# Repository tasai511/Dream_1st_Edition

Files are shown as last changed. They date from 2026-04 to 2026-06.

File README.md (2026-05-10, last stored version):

# ドリーム1号 素振り記録アプリ

素振り練習用デバイス「ドリーム1号」の記録用PWAです。HTML / CSS / JavaScriptのみで構成され、アプリ本体は `app/` フォルダに入っています。

## できること

- 名前とバットを複数登録
- 日付、名前、バット、素振り回数、平均スコア、ベストスコアを記録
- 同じ日付・名前・バットの記録は自動で合算
- 平均スコアは回数による加重平均で計算
- ベストスコアは最大値を採用
- 最近の入力履歴から編集・削除
- 期間、名前、バットで絞り込んだグラフ表示
- CSVエクスポート / インポート
- オフライン動作

## GitHub Pagesで公開する方法

1. このリポジトリをGitHubへpushします。
2. GitHubのリポジトリ画面で `Settings` を開きます。
3. `Pages` を開きます。
4. `Build and deployment` の `Source` で `Deploy from a branch` を選びます。
5. `Branch` で公開したいブランチと `/root` を選び、保存します。
6. 表示されたURLを開くと、自動で `app/` のアプリが開きます。

アプリを直接開く場合は、GitHub PagesのURL末尾に `/app/` を付けてください。

## PWAとしてホーム画面に追加する方法

### iPhone / iPad

1. SafariでGitHub PagesのURLを開きます。
2. 共有ボタンを押します。
3. `ホーム画面に追加` を選びます。
4. 名前を確認して追加します。

### Android

1. ChromeでGitHub PagesのURLを開きます。
2. メニューから `ホーム画面に追加` または `アプリをインストール` を選びます。
3. 確認して追加します。

## CSVエクスポート / インポート

### エクスポート

`CSVエクスポート` ボタンを押すと、全記録をCSVファイルとして保存します。CSVには以下の列が含まれます。

- 名前
- バット
- 日付
- 回数
- 平均
- ベスト

### インポート

`CSVインポート` からCSVファイルを選ぶと、記録を復元できます。既存データと同じ日付・名前・バットの行は合算されます。不正な行はスキップされ、読み込み後にスキップ件数が表示されます。

## データ保存について

データはすべて端末ローカルのIndexedDBに保存されます。サーバー保存、ログイン、クラウド同期はありません。

端末を変更する場合やブラウザのデータを消す場合は、事前にCSVエクスポートでバックアップしてください。新しい端末ではCSVインポートで移行できます。

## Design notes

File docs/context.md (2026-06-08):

# Dream-1 コンテキスト

## 概要

Dream-1 は、バットの素振りを楽しく続けるための小型スイングモチベーションデバイスです。

科学的な計測器ではありません。真のバットヘッドスピードや打球速度を測るものではなく、同じユーザー、同じバット、同じ装着位置での相対比較を目的にしたトレーニング用スコアを出します。

主な目的:

- 素振り回数を増やす
- 良いスイングの体感を数字で補助する
- 同じ条件下での自己比較をしやすくする
- 子供でもスコアが出て楽しい体験にする

Dream-1 は、正確に測る装置ではなく、良い練習を増やす装置である。

---

## 記録アプリ: Swing Log 現行実装

Dream-1 の記録アプリは、厳密なトレーニング評価ではなく「素振りを続けたくなる記録とバッジ収集」のための PWA として実装している。

重視すること:

- 毎日少しでも振りたくなる
- あと少しで取れる感を出す
- 回数、平均、ベスト、練習日数の積み上げを見せる
- 他人比較ではなく、同じ名前、同じバット、同じ端末内での自己比較を中心にする
- Dream-1 は厳密フォーム解析機ではなく、素振りを楽しく続けるための道具として扱う

### 技術構成

- 実装本体は `app/src/App.jsx`
- React 18 + Vite
- CSS は `app/src/styles.css`
- PWA 用に `app/public/manifest.webmanifest` と `app/public/service-worker.js` を使う
- service worker は静的アセット、画像、音声を cache する
- データ保存は IndexedDB ではなく `localStorage`
- storage key は `dream1-swing-tracker-v1`
- サーバー保存、ログイン、クラウド同期はない

### アプリデータ

`localStorage` に保存する DB は概ね以下。

```ts
type AppDb = {
  activeName: string;
  names: string[];
  nameColors: Record<string, string>;
  bats: string[];
  batColors: Record<string, string>;
  defaultBat: string;
  theme: string;
  fontTheme: string;
  records: SwingRecord[];
  seasonEventSettings: SeasonEventSettings;
  badgeRewardGoal: string;
  badgeRewardText: string;
  testInputDefaults: boolean;
  testRandomGeneration: boolean;
  testDate: string | null;
};

type SwingRecord = {
  id: string;
  name: string;
  bat: string;
  date: string;  // YYYY-MM-DD
  count: number;
  avg: number;   // 0..999
  best: number;  // 0..999
};

type SeasonEventSettings = Record<
  "spring" | "summer" | "winter",
  { startMonth: number; startDay: number; endMonth: number; endDay: number }
>;
```

名前とバットが1件以上ない場合は、設定画面へ誘導する。
記録は同じ日付、名前、バットでも物理的には結合せず、`records` に追加する。表示時に日付別、バット別へ集計する。

### 入力と CSV

ホーム画面から以下を入力する。

- バット
- 回数
- 平均スコア
- ベストスコア

保存時の丸め:

- `count`: 最低 `1`
- `avg`: `0..999` に clamp
- `best`: `0..999` に clamp

CSV 出力:

```csv
name,bat,date,count,avg,best
```

CSV 読込では、存在しない名前やバットを自動追加し、各行を新しい record として追加する。既存 record との物理的な重複統合はしない。

### 集計

日次集計:

```ts
dailyCount = sum(record.count)
dailyAvg = round(sum(record.avg * record.count) / dailyCount)
dailyBest = max(record.best)
dailyBats = unique(record.bat)
```

バット別集計も同じ考え方で、バットごとに回数合計、回数加重平均、ベスト最大値を出す。

期間集計:

- 今日: 対象日だけ
- 今週: 月曜始まり、日曜終わり
- 今月: 暦月
- チャレンジ画面の今年: 初回記録日を起点にした1年サイクル
- 年間バッジ判定: 暦年単位

期間平均は、期間内 record の `avg * count` を回数で割った加重平均。
練習日数は、`count > 0` の日数。

### 画面構成

下部ナビゲーション:

- ホーム
- チャレンジ
- バッジ
- データ
- 設定

ホーム:

- 日付選択
- スコア入力
- 今日または選択日の回数、平均、ベスト
- 取得バッジ
- バット別の回数、平均、ベスト
- 記録追加時のスコアアニメーションと初取得バッジポップアップ

チャレンジ:

- 今週、今月、今年のスイング数
- 今週、今月、今年の練習日数
- 選択バットの過去最高平均、過去最高ベスト

バッジ:

- バッジポイント
- 目標ポイントとごほうび入力
- コレクション一覧
- カテゴリ filter: スイング数、練習日数、平均、ベスト、すべて
- レア度ごとの表示

データ:

- 毎日、毎週、毎月のグラフ
- スイング数グラフ
- 平均/ベストのスコアグラフ
- バット filter

設定:

- 名前の登録、切り替え、削除、色設定
- バットの登録、削除、色設定、デフォルトバット
- CSV 出力、CSV 読込
- 全データ削除
- デモデータ作成
- テストモード

### バッジ

バッジ取得履歴は別テーブルに保存しない。
`records` から `badgesFor()` で毎回再計算し、`collectBadgeCounts()` でコレクション表示用の個数に変換する。

レア度:

```ts
type BadgeRarity = "D" | "C" | "B" | "A" | "S" | "SS";

const rarityPoint = {
  D: 1,
  C: 2,
  B: 5,
  A: 10,
  S: 25,
  SS: 100,
};
```

レア度名:

- D: Dream
- C: Challenge
- B: Brave
- A: Ace
- S: Star
- SS: Super Star

実装済みバッジ:

| 種別 | 指標 | 閾値 |
| --- | --- | --- |
| 今日 | スイング数 | 25, 50, 75, 100 |
| 今日 | 平均 | 250, 350, 450, 550, 650, 750 |
| 今日 | ベスト | 350, 450, 550, 650, 750, 850 |
| 今週 | スイング数 | 125, 250, 375, 500 |
| 今週 | 練習日数 | 1, 2, 3, 4, 5 |
| 今月 | スイング数 | 500, 1000, 1500, 2000 |
| 今月 | 練習日数 | 4, 8, 12, 16, 20 |
| 今年 | スイング数 | 6000, 12000, 18000, 24000 |
| 今年 | 練習日数 | 50, 100, 150, 200, 225, 250 |
| 初突破 | バット別過去最高平均 | 400, 500, 600, 700, 750, 800 |
| 初突破 | バット別過去最高ベスト | 500, 600, 700, 800, 850, 900 |

`unique` はコレクション上で1個まで。
`repeatable` は取得回数分だけ個数とポイントに加算する。
初突破系はバットごとの過去最高更新時に、その閾値を初めて超えた日に付与する。

### テスト機能

設定画面からデモデータを作成できる。
テストモードでは任意の日付へ進め、未入力日の練習記録を自動生成できる。
この機能は UI とバッジ演出の検証用で、本番の記録仕様とは分けて考える。

---

## 非交渉原則

- 子供が振って楽しいことを最優先する
- 999 は簡単に出さない
- 普通のスイングで無反応にしすぎない
- 変な振り方を高得点にしない
- 電池寿命を著しく削る変更は避ける
- スコアの納得感を、物理精度より優先する

---

## 参考スコアレンジ

現時点の体感チューニング目安:

- 普通の子供スイング: 320〜520
- 良いスイング: 550〜750
- かなり良いスイング: 800+
- 999 は稀

このレンジは絶対値ではない。  
同じユーザー、同じバット、同じ装着位置で比較したときに納得感が出ることを優先する。

スコアの思想:

- 高得点 = 強く、早く、再現性高くインパクトを作れそうなスイング
- 低得点 = 遠回り、遅い、ブレる、弱いスイング
- 大ぶり = 力強いスイングではなく、遠回りで当たりにくそうなスイング
- 良いスイング = 十分な加速エリアの中で角速度も高く出る、鋭く振り切れたスイング

---

## ハードウェア

### MCU

- ATtiny3226
- 10MHz
- Arduino framework
- PlatformIO

### IMU

- LSM6DSV80X
- SPI 接続
- CS: PA4
- FIFO と割り込みを使用
- タップ検出も IMU 側から取得する

### ブザー

- 圧電ブザー
- 差動駆動
- BUZZER_P: PA6
- BUZZER_N: PA7

注意:

- Serial TX はブザーやピン割り当てと干渉し得る
- 実運用では Serial 接続を前提にしない
- デバッグ出力は本番経路に入れない

### 7セグ LED

- 3桁 7セグ LED
- common cathode
- multiplex 駆動

セグメント:

- SEG_A: PB0
- SEG_B: PB2
- SEG_C: PB4
- SEG_D: PB3
- SEG_E: PB1
- SEG_F: PB5
- SEG_G: PC0

桁選択:

- DIGIT_1: PC1
- DIGIT_2: PC2
- DIGIT_3: PC3

表示方針:

- 通常は消灯
- スコア、平均、回数など必要なときだけ短時間表示
- ブザー動作中は表示更新よりブザーを優先する
- 表示ロジックは単純で決定的に保つ

### 電源

- CR2450 コイン電池
- 低消費電力が重要
- 不要な active 時間を増やさない
- idle 時は sleep を使う
- 長時間無操作で最終 sleep に入る

---

## 現在の製品挙動

### 通常状態

- 起動後に短時間キャリブレーションする
- キャリブレーション中は電池残量目安を表示する
- その後は Monitor 状態で IMU を監視する
- 有効なスイングを検出すると Capturing 状態に入り、ピークや特徴量を記録する
- スイング終了後、スコアを計算して表示する
- 表示時間終了後、Monitor に戻る

### ブザー

スイング成立時にブザーを鳴らす。

- ベスト更新: 3回
- 平均以上: 2回
- 平均未満: 1回
- 一定回数ごとの節目: milestone beep

この仕様は現在の実装を正とする。

### 表示

- スイング成立後、スコアを短時間表示する
- 低スコアでもスイングとして成立していれば `100` 以上で表示する
- 無効な動きは表示しない
- Single tap ではスイング回数を表示する
- Double tap では平均スコアを1秒表示し、その後ベストスコアを1秒表示する
- Double tap の平均/ベスト表示中は表示の安定を優先し、スイング検出は受け付けない
- 表示中やスコア直後はタップ誤検出を抑えるために mute 時間を設ける

### タップ

- タップはスコア計算には使わない
- スイング検出とは別系統の入力として扱う
- Single / Double のイベントを扱う
- Double tap は平均表示からベスト表示への2段表示
- 通常スイングのフォロースルーがタップ扱いになりにくいよう、表示直後やスコア直後はタップを抑制する

---

## スコアの意味

スコアは物理量ではありません。以下のような動きの傾向を IMU から拾い、0〜999 の範囲に収めた実用スコアです。

高くしたい動き:

- 十分な角速度ピークがある
- 一定以上の加速度がある程度続いている
- 回転と加速度の両方が出ている
- 同じ条件下で、より強く鋭く振れている

低くしたい動き:

- 弱い
- 遅い
- 回転だけ、または加速度だけに偏っている
- 一瞬だけの衝撃
- 小さい手振り
- ランダムな持ち替え、振動、置いた衝撃

---

## スイング検出

### 開始条件

Monitor 中に以下のような意味のある動きが出たら Capturing を開始する。

- `strength >= kCaptureStartStrength` (`2400`)
- かつ、`gyroMagnitudeRaw >= kCaptureStartGyroRaw` (`900`) または `dynamicAccelMg >= kCaptureStartAccelMg` (`1800`)

`strength` は概ね以下の合成値:

```cpp
gyroMagnitudeRaw + dynamicAccelMg * 4
```

ゆっくりした持ち替えや小さい動きは開始しにくくする。

### キャプチャ中に記録する値

スイング成立判定とスコア再計算のために、主に以下を記録する。

- `gyroPeakRaw`
- `accelPeakMg`
- `firstGyroStrongTimeMs`
- `maxAccelRiseMs`
- `swingAccelAreaMgMs`
- `capturePeakStrength`

スコア計算時は、キャプチャサンプルから `ScoreWindow` を作り直し、その範囲内で `gyroPeakRaw` と `swingAccelAreaMgMs` を再計算する。

### 終了条件

以下のどちらかでキャプチャを終了する。

- 最大キャプチャ時間 `kCaptureMaxMs` (`900 ms`) に達した
- 最小キャプチャ時間 `kCaptureMinMs` (`80 ms`) を超え、`strength` が `capturePeakStrength * kCaptureEndDropPct / 100` (`70%`) 以下になった

### 無効化

`swingEvidence()` によって、動きがスイングらしいかを確認する。

現在の evidence は合計 `6` 点以上でスイング成立。

- スイング時間: `160 ms` 以上で +2、`80 ms` 以上で +1
- gyro peak: `gyroPeakRaw >= 900` で +2
- accel peak: `2000 mg` 以上で +2、`1000 mg` 以上で +1
- accel rise 時間: `35 ms` 以上で +2、`15 ms` 以上で +1
- 強い gyro が一度でも出たら +1
- `capturePeakStrength >= 1800` で +1

`accel rise` はスコアには使わない。  
加速度が一瞬の衝撃ではなく、ある程度立ち上がった動きかを確認するための evidence 専用指標として使う。

低スコア救済は使わない。  
最終スコアが `100` に届いた場合だけスコア表示する。  

---

## スコア計算

現在のスコアは `finishCapture()` で `gyroPeakScore()` と `swingAccelAreaScore()` を計算し、`scoreFromComponents()` で合算する。

構成:

```cpp
score = gyroPeakScore();          // max 500
score += swingAccelAreaScore();   // max 500
score = min(score, 999);
```

整数演算中心で、float は使わない。

採点に入る条件:

- `swingEvidence()` が `6` 点以上
- score が `100` 以上

この条件を満たさない場合は no score。

### ScoreWindow

スコア対象範囲はキャプチャ全体ではなく、キャプチャサンプルから作る `ScoreWindow` で決める。
一時的な山で閉じないよう、まず `scoreStartMs` 以降の最大加速度ピークを確定し、その後の落ち込みで `scoreEndMs` を決める。

- `scoreStartMs`: `dynamicAccelMg > 1000 mg` になった最初のサンプル
- `accelPeakMs`: `ScoreWindow` 内での最大加速度サンプル
- `scoreEndMs`: 加速度ピーク後、ピークから `max(ピークの10%, 1000mg)` 以上落ちた時点の直前サンプル。直前サンプルがピークより前ならピーク時刻にする

つまり、スコア範囲は「1000mg を超えて加速が始まったところ」から「加速度ピーク後に明確に落ち始める直前」まで。
1000mg を下回るまで待たない。

`scoreStartMs` は pre capture sample を含むため、グラフ上では負の時刻になることがある。

### gyroPeakScore

`ScoreWindow` 内の角速度ピークを見る。
グローバルなキャプチャ全体の gyro peak ではなく、加速エリア中の最大 gyro を使う。

- 最大 500 点
- gyro full は実測に合わせて `7000 dps`
- IMU の 4000 dps 設定に合わせて `140 mdps/LSB` として換算する
- 7000 dps 以上は 500 点に clamp する

考え方:

- MLB Statcast では 75 mph 以上を fast swing として扱う
- MLB 上位選手の平均 bat speed は 80 mph 前後に達する
- bat speed 80〜85 mph を sweet spot 半径およそ 0.75 m で角速度換算すると約 2700〜2900 dps
- ただし Dream-1 は単一軸ではなく3軸合成の `gyroMagnitudeRaw` を使うため、単純な角速度換算より大きめに出る
- 3000〜4500 dps では子供や軽めのスイングでも上限に届きやすかったため、Dream-1 の実測レンジに合わせて `7000 dps` を使う
- この値は実測ベースの仮置き。上手い人で Gyro 側が簡単に 500 点へ張り付く場合はさらに上げる候補がある

### swingAccelAreaScore

`ScoreWindow` 内に乗った dynamic accel の積算を見る。

```cpp
area = sum((dynamicAccelMg - offset) * dt)
score = area / fullArea * 500
```

手首だけの一瞬の入力ではなく、スイング中に加速度が乗って続いたかを見る。  
現在は `offset` を初めて超えた時刻から、加速度ピーク後に明確に落ち始める直前までの offset 超過分を積算する。

`offset` は `1000 mg`。  
小さい揺れ、構え、ぶらぶらを積算しにくくしつつ、普通のスイングが `0` になりにくい値として実測から置いている。

`fullArea` は `800000 mg*ms`。
これは公開データから直接導いた物理定数ではなく、Dream-1 の実測ベースの仮置き。  
加速度スコア範囲を広げたことで `600000 mg*ms` では軽いバットの強いスイングが上限に張り付きやすくなったため、飽和を少し抑える値として `800000 mg*ms` を採用している。
配点は SwingAccel 側を 500 点、Gyro 側を 500 点にしている。

今後、通常のバットでも簡単に SwingAccel 側が 500 点へ張り付く場合は `900000〜1000000 mg*ms` 程度へ上げる候補がある。逆に一般ユーザーで伸びなさすぎる場合は `700000 mg*ms` 程度へ下げる候補がある。

### accel rise

スイング時間に対して加速度がピークへ向かって立ち上がった時間を見る。

- スコア補正には使わない
- `swingEvidence()` のために記録する

`maxAccelRiseMs` は固定閾値以上の時間ではなく、dynamic accel が立ち上がってからピーク後に減少へ転じるまでの時間として記録する。  
ノイズで1サンプルだけ下がっても減少扱いにしないよう、小さい変化は無視し、連続した減少で判定する。

加速上昇の開始は `kAccelRiseStartMg` 以上で見る。  
これはスイング成立判定用の accel rise 判定であり、スイング開始判定用の `kCaptureStartAccelMg` とは別に扱う。

---

## スコア下限

`scoreFromComponents()` が返すスコアを、そのまま表示、平均、ベスト更新、ブザー判定に使う。

現在の下限:

- score `100` 未満: no score
- score `100` 以上: 採点成立

ただし、無効な動きは表示しない。

---

## 実装構成

### `src/main.cpp`

- 状態遷移
- キャリブレーション
- スイング開始/終了判定
- ピーク記録
- スコア計算
- タップ処理
- 省電力制御

現在はスコア処理も `main.cpp` 内にある。  
将来的に大きくなる場合は `score.cpp / score.h` に分けてもよいが、現状では軽量さと見通しを優先する。

### `telemetry_best_swing_graph.html`

- EEPROM に保存した best swing telemetry を可視化する解析用 HTML
- `score start`、`accel score end`、`accel peak`、`end judge` をグラフに出す
- `gyro score peak` は `ScoreWindow` 内で実際に見えている最大 gyro sample を表示する
- C++ 側では best telemetry 保存時に score gyro peak sample を優先して残す

### `src/imu.cpp` / `include/imu.h`

- IMU 初期化
- FIFO/割り込み処理
- motion sample 読み出し
- tap event 読み出し
- sleep mode 移行

### `src/display.cpp` / `include/display.h`

- 7セグ表示
- multiplex 更新
- 数値表示
- 表示 timeout
- 消灯

### `src/buzzer.cpp` / `include/buzzer.h`

- ブザー初期化
- beep
- milestone beep
- ブザー波形生成
- beep 中はブザーを優先し、短時間ブロッキングしてよい
- off

### `include/tap.h`

- `TapEvent`
- `None`
- `Single`
- `Double`

---

## メインループ方針

- 通常の監視、表示、スイング処理では長い `delay()` を入れない
- スイング成立直後の beep は例外として、ブザーを優先して短時間ブロッキングしてよい
- ブザー動作中は表示更新や IMU 読み出しよりブザー出力を優先する
- 表示は `Display::update()` で継続更新する
- IMU 割り込みがあるときにサンプルを読む
- 割り込みが詰まった場合は一定時間後に強制読み出しする
- Monitor 中で動きがなければ idle sleep に入る
- 長時間無操作なら final sleep に入る

---

## コーディング方針

必須:

- Arduino style の `setup()` / `loop()` を使う
- 整数演算中心
- RAM 使用量を小さく保つ
- コードサイズを増やしすぎない
- 本番経路に Serial debug を入れない
- 状態遷移、表示、ブザー、省電力処理を不用意に崩さない

避ける:

- float 多用
- スイング監視中の長い blocking wait
- 重いライブラリ
- 複雑すぎるゲート処理
- 科学計測器のような絶対精度を目指すこと

---

## チューニング方針

まず触る候補:

- gyro/accel の開始閾値
- `swingAccelAreaScore()` の offset
- `gyroPeakScore()` の full dps
- `swingAccelAreaScore()` の fullArea
- `kGyroPeakScoreMax` / `kSwingAccelAreaScoreMax` の配点比率
- `kScoreAccelDropPct` / `kScoreAccelDropMinMg` による score end 判定

チューニング時の注意:

- 「無反応」と「100連発」は同じ対策で悪化しやすい
- 小さい動きの誤検出を減らしつつ、大ぶり低スコアは表示したい
- 999 は「速いだけ」では出ないようにする
- 子供が普通に振ったときに点が出なさすぎる状態は避ける
- 装着位置やバット長さで値は変わるため、補正は強くしすぎない

---

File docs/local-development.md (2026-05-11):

# このPCで開発を続ける手順

このプロジェクトは、ファームウェア、記録用PWA、CADデータが同じリポジトリに入っています。

## 記録用アプリを開く

このPCでは `python` や `node` が見つからないため、PowerShellだけで動くローカルサーバーを用意しています。

```powershell
Set-ExecutionPolicy -Scope Process -ExecutionPolicy Bypass
.\tools\serve-local.ps1
```

起動したら、ブラウザで次を開きます。

```text
http://localhost:5173/app/
```

ポートを変えたい場合:

```powershell
.\tools\serve-local.ps1 -Port 5174
```

止めるときは、サーバーを起動しているPowerShellで `Ctrl+C` を押します。

## 記録データについて

記録用アプリのデータはブラウザのIndexedDBに保存されます。PC、ブラウザ、スマホを変える前には、アプリ内の「CSVエクスポート」でバックアップしてください。移行先では「CSVインポート」で戻せます。

## ファームウェアをビルドする

PlatformIOはこのPCで動作確認済みです。

```powershell
& "$env:USERPROFILE\.platformio\penv\Scripts\pio.exe" run
```

現在の設定は `platformio.ini` にあり、書き込みポートは `COM3` です。

## 確認済み

- PlatformIOビルド: 成功
- 記録用アプリ: `app/` に配置済み
- ローカル確認用サーバー: `tools/serve-local.ps1`

## 注意

PowerShellで日本語ファイルを `Get-Content` すると、環境によって文字化けして見える場合があります。ブラウザやGit diffでは正常に読めることがあります。

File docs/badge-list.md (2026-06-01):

# シンプル版バッジ一覧

## 基本方針

バッジは、以下の4カテゴリに整理する。

| カテゴリ | 評価するもの |
| --- | --- |
| スイング数 | たくさん振った |
| 練習日数 | 続けて練習した |
| 平均 | 今日の平均スコア・バット別の平均初突破 |
| ベスト | 今日のベストスコア・バット別のベスト初突破 |

複合条件、週間チャレンジ、月間チャレンジ、月間総合、バランス系は作らない。

## レア度とpt

| レア度 | pt |
| --- | -: |
| D | 1 |
| C | 2 |
| B | 5 |
| A | 10 |
| S | 25 |
| SS | 100 |

## スイング数バッジ

### 今日のスイング

| レア度 | 名前 | 条件 | pt |
| --- | --- | --- | -: |
| D | 今日のスイング 25回 | 25回以上 | 1 |
| D | 今日のスイング 50回 | 50回以上 | 1 |
| C | 今日のスイング 75回 | 75回以上 | 2 |
| B | 今日のスイング 100回 | 100回以上 | 5 |

### 今週のスイング

| レア度 | 名前 | 条件 | pt |
| --- | --- | --- | -: |
| D | 今週のスイング 125回 | 125回以上 | 1 |
| C | 今週のスイング 250回 | 250回以上 | 2 |
| B | 今週のスイング 375回 | 375回以上 | 5 |
| A | 今週のスイング 500回 | 500回以上 | 10 |

### 今月のスイング

| レア度 | 名前 | 条件 | pt |
| --- | --- | --- | -: |
| C | 今月のスイング 500回 | 500回以上 | 2 |
| B | 今月のスイング 1000回 | 1000回以上 | 5 |
| A | 今月のスイング 1500回 | 1500回以上 | 10 |
| S | 今月のスイング 2000回 | 2000回以上 | 25 |

### 今年のスイング

| レア度 | 名前 | 条件 | pt |
| --- | --- | --- | -: |
| B | 今年のスイング 6000回 | 今年6000回以上 | 5 |
| A | 今年のスイング 12000回 | 今年12000回以上 | 10 |
| S | 今年のスイング 18000回 | 今年18000回以上 | 25 |
| SS | 今年のスイング 24000回 | 今年24000回以上 | 100 |

## 練習日数バッジ

### 今週の練習日数

| レア度 | 名前 | 条件 | pt |
| --- | --- | --- | -: |
| D | 今週の練習日数 1日 | 1日以上 | 1 |
| C | 今週の練習日数 2日 | 2日以上 | 2 |
| B | 今週の練習日数 3日 | 3日以上 | 5 |
| A | 今週の練習日数 4日 | 4日以上 | 10 |
| S | 今週の練習日数 5日 | 5日以上 | 25 |

### 今月の練習日数

| レア度 | 名前 | 条件 | pt |
| --- | --- | --- | -: |
| D | 今月の練習日数 4日 | 4日以上 | 1 |
| C | 今月の練習日数 8日 | 8日以上 | 2 |
| B | 今月の練習日数 12日 | 12日以上 | 5 |
| A | 今月の練習日数 16日 | 16日以上 | 10 |
| S | 今月の練習日数 20日 | 20日以上 | 25 |

### 今年の練習日数

| レア度 | 名前 | 条件 | pt |
| --- | --- | --- | -: |
| D | 今年の練習日数 50日 | 今年練習50日以上 | 1 |
| C | 今年の練習日数 100日 | 今年練習100日以上 | 2 |
| B | 今年の練習日数 150日 | 今年練習150日以上 | 5 |
| A | 今年の練習日数 200日 | 今年練習200日以上 | 10 |
| S | 今年の練習日数 225日 | 今年練習225日以上 | 25 |
| SS | 今年の練習日数 250日 | 今年練習250日以上 | 100 |

## 平均バッジ

### 今日の平均スコア

| レア度 | 名前 | 条件 | pt |
| --- | --- | --- | -: |
| D | 今日の平均スコア 250 | 平均250以上 | 1 |
| D | 今日の平均スコア 350 | 平均350以上 | 1 |
| C | 今日の平均スコア 450 | 平均450以上 | 2 |
| B | 今日の平均スコア 550 | 平均550以上 | 5 |
| A | 今日の平均スコア 650 | 平均650以上 | 10 |
| S | 今日の平均スコア 750 | 平均750以上 | 25 |

### 平均初突破

バットごとの1日平均スコアの最高値が各閾値に初めて到達した時点で獲得する。
バットが違えば同じバッジを何回でも獲得できる。

| レア度 | 名前 | 条件 | pt |
| --- | --- | --- | -: |
| D | 初突破 平均 400点 | そのバットでの平均400以上 | 1 |
| C | 初突破 平均 500点 | そのバットでの平均500以上 | 2 |
| B | 初突破 平均 600点 | そのバットでの平均600以上 | 5 |
| A | 初突破 平均 700点 | そのバットでの平均700以上 | 10 |
| S | 初突破 平均 750点 | そのバットでの平均750以上 | 25 |
| SS | 初突破 平均 800点 | そのバットでの平均800以上 | 100 |

## ベストバッジ

### 今日のベストスコア

| レア度 | 名前 | 条件 | pt |
| --- | --- | --- | -: |
| D | 今日のベストスコア 350 | ベスト350以上 | 1 |
| D | 今日のベストスコア 450 | ベスト450以上 | 1 |
| C | 今日のベストスコア 550 | ベスト550以上 | 2 |
| B | 今日のベストスコア 650 | ベスト650以上 | 5 |
| A | 今日のベストスコア 750 | ベスト750以上 | 10 |
| S | 今日のベストスコア 850 | ベスト850以上 | 25 |

### ベスト初突破

バットごとの1日ベストスコアの最高値が各閾値に初めて到達した時点で獲得する。
バットが違えば同じバッジを何回でも獲得できる。

| レア度 | 名前 | 条件 | pt |
| --- | --- | --- | -: |
| D | 初突破 ベスト 500点 | そのバットでのベスト500以上 | 1 |
| C | 初突破 ベスト 600点 | そのバットでのベスト600以上 | 2 |
| B | 初突破 ベスト 700点 | そのバットでのベスト700以上 | 5 |
| A | 初突破 ベスト 800点 | そのバットでのベスト800以上 | 10 |
| S | 初突破 ベスト 850点 | そのバットでのベスト850以上 | 25 |
| SS | 初突破 ベスト 900点 | そのバットでのベスト900以上 | 100 |

## 実装メモ

- スイング数、練習日数、ベストは一度獲得したら獲得済みとして扱う。
- 平均スコア系は、スコアが下がって条件を満たさなくなったら獲得を外す。
- 初突破系はバットごとに判定する。同じ閾値でもバットが違えば別回として獲得する。
- ホームは今日の記録、チャレンジは進捗、バッジはコレクション、設定は既存機能を維持する。

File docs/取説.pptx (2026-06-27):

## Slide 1

取扱説明書

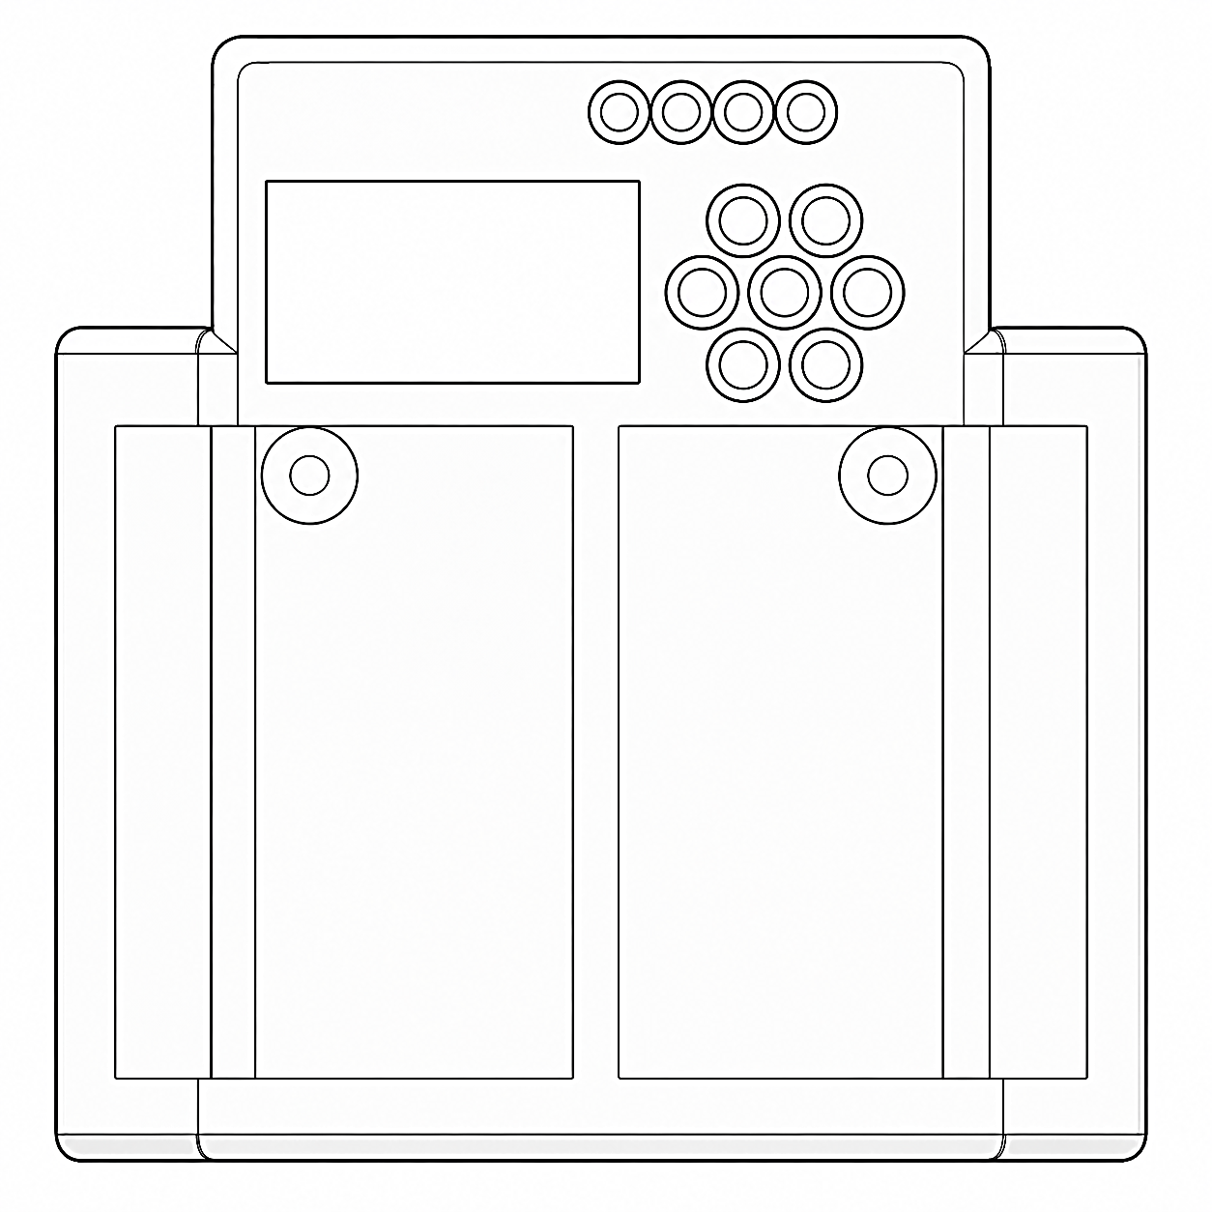
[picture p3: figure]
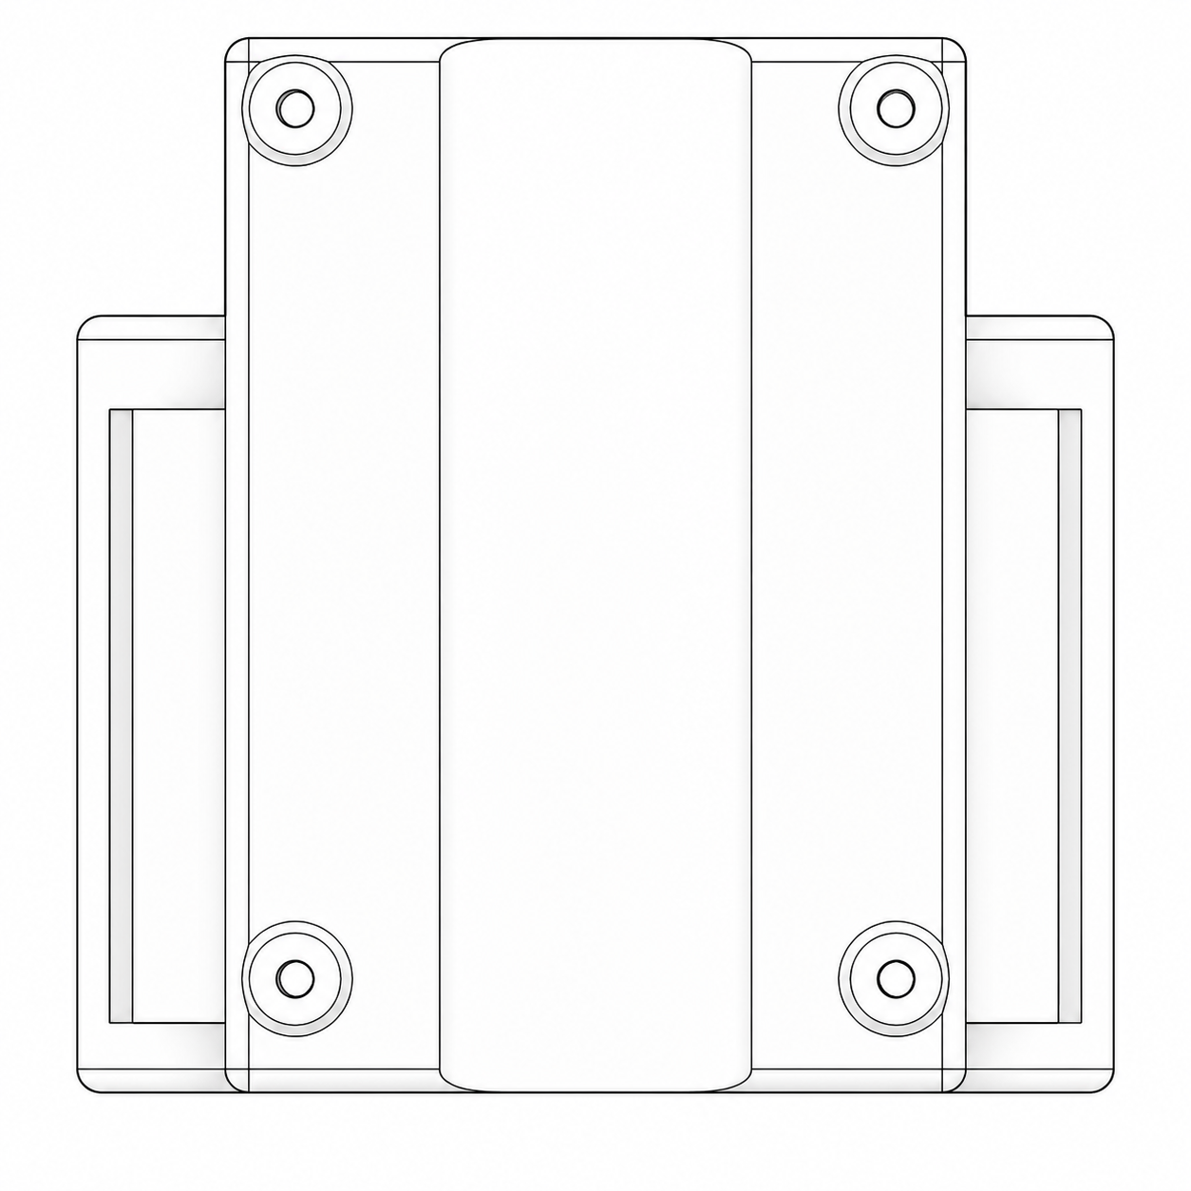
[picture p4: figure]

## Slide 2

仕組み

少年野球用
素振り練習補助装置

子ども達が素振りを「続けたくなる」ための小型デバイスです。

いつものバットに取り付けて素振りすることで、スイングを100～999点のスコアで見える化します。
専用の記録アプリと合わせて使うことで素振り練習をゲーム化し、楽しみながら継続することをサポートします。

本体に内蔵されたセンサーで、スイング中の2つの動きを読み取ります。
1. 加速度
どれだけ力強くバットを動かしたか
2. 回転速度
どれだけ速くバットが回ったか
スコアは、強い加速度がどれだけ続いたかと、
スイング中の回転速度の高さをもとに計算しています。
高得点は、力強く、速く、しっかり振れたスイングの目安です。
※スコアは本格的な計測値ではなく、同じバット・同じ取り付け位置での自己比較用です。

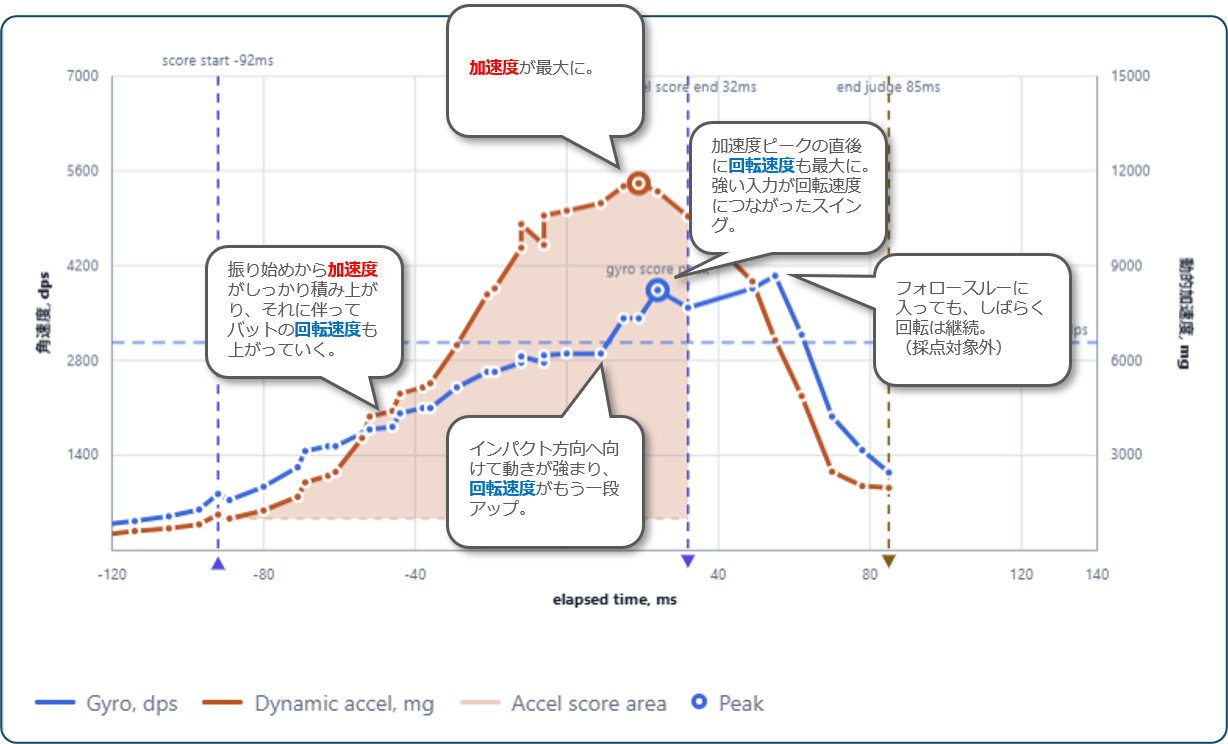
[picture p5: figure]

例）751点のスイング

329点のスイング

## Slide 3

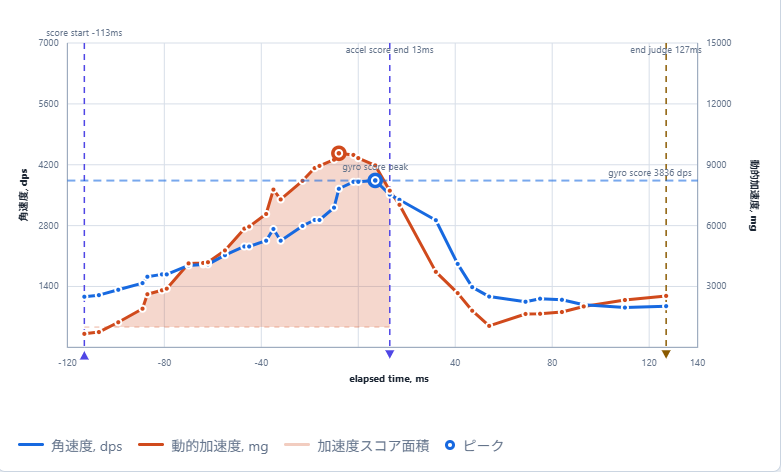
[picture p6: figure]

スコア＝757点
振り始めからどんどん加速し、ピークを迎えた直後に回転速度も最大に達している。

加速の強さ、加速の継続時間が十分で、その勢いでバットを回転させているのでヘッドスピードはかなり早いと想定される。
加速度が高い割に回転速度は抑えられており、加速エネルギーはすべて回転に向かわず「並進（レベルスイング）」の区間がある。
高得点。

スコア＝470点
加速が弱く、長く続いている割にはピークが低い。

力を抜いてゆっくり振ったスイング。

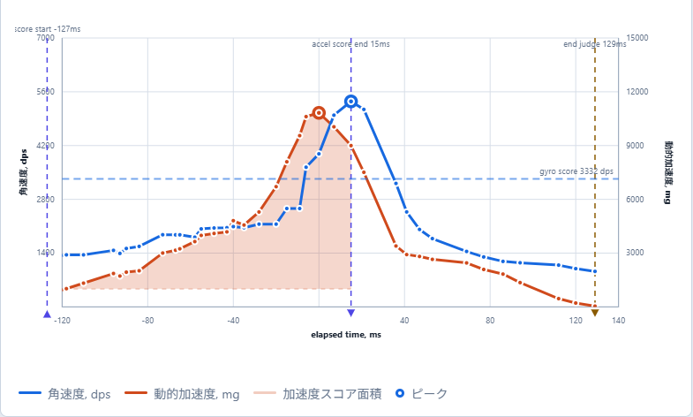
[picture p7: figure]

スコア＝680点
加速度のピークはかなり高いが、立ち上がりが遅く、スイングの終盤で瞬間的に加速しただけでヘッドスピードはそんなに早くないと想定される。

それほど加速していない状態から急激に回転速度があがっており、加速がすべて回転に使われていることから「その場で小さくバットを回転させただけ」に見える。

典型的な「手振りスイング」。

スコア＝655点
加速は十分に継続しているが、回転速度がそれについてきていない。
「加速しているにも関わらず回転していない」は典型的な「ドアスイング」。

身体からバットが離れて回転の中心が大きく動いていると想定される。

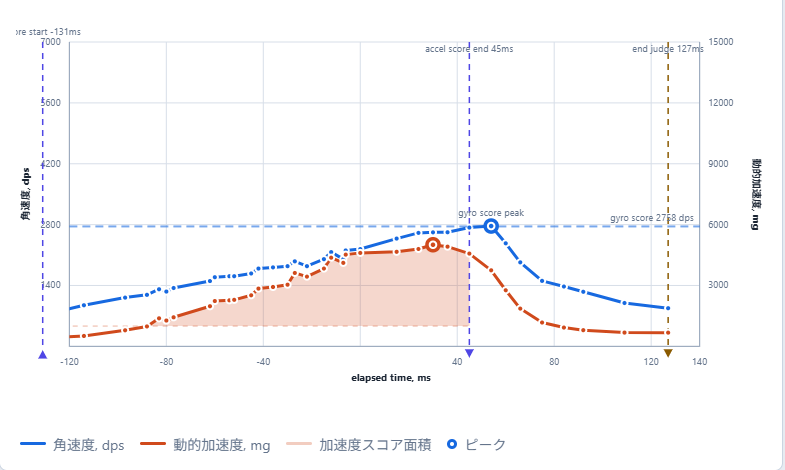
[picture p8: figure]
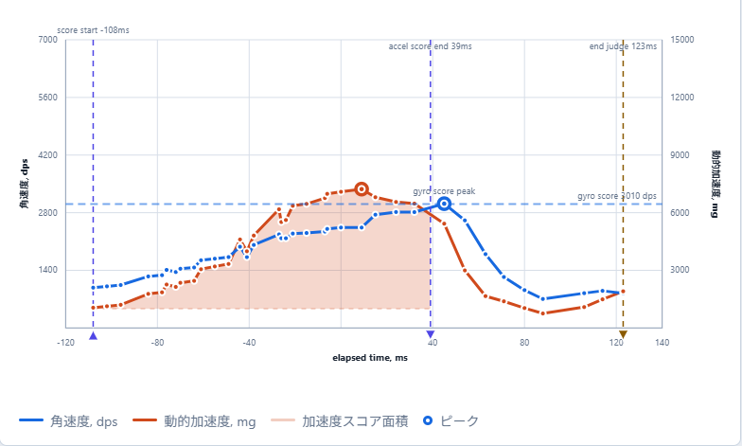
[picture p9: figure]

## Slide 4

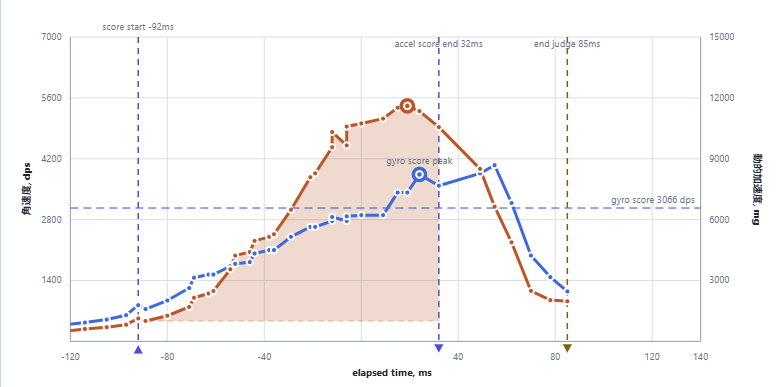
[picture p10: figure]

加速度が最大に。

インパクトへ向けて動きが強まり、
回転速度がもう一段アップ。

加速度ピークの直後に回転速度も最大に。
強い入力が回転速度につながったスイング。

振り始めから加速度がしっかり積み上がり、それに伴ってバットの回転速度も上がっていく。

フォロースルーに入っても、しばらく回転は継続。
（採点対象外）

装置内部では、
の面積と
の高さ
を元にスコアを算出しています。

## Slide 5

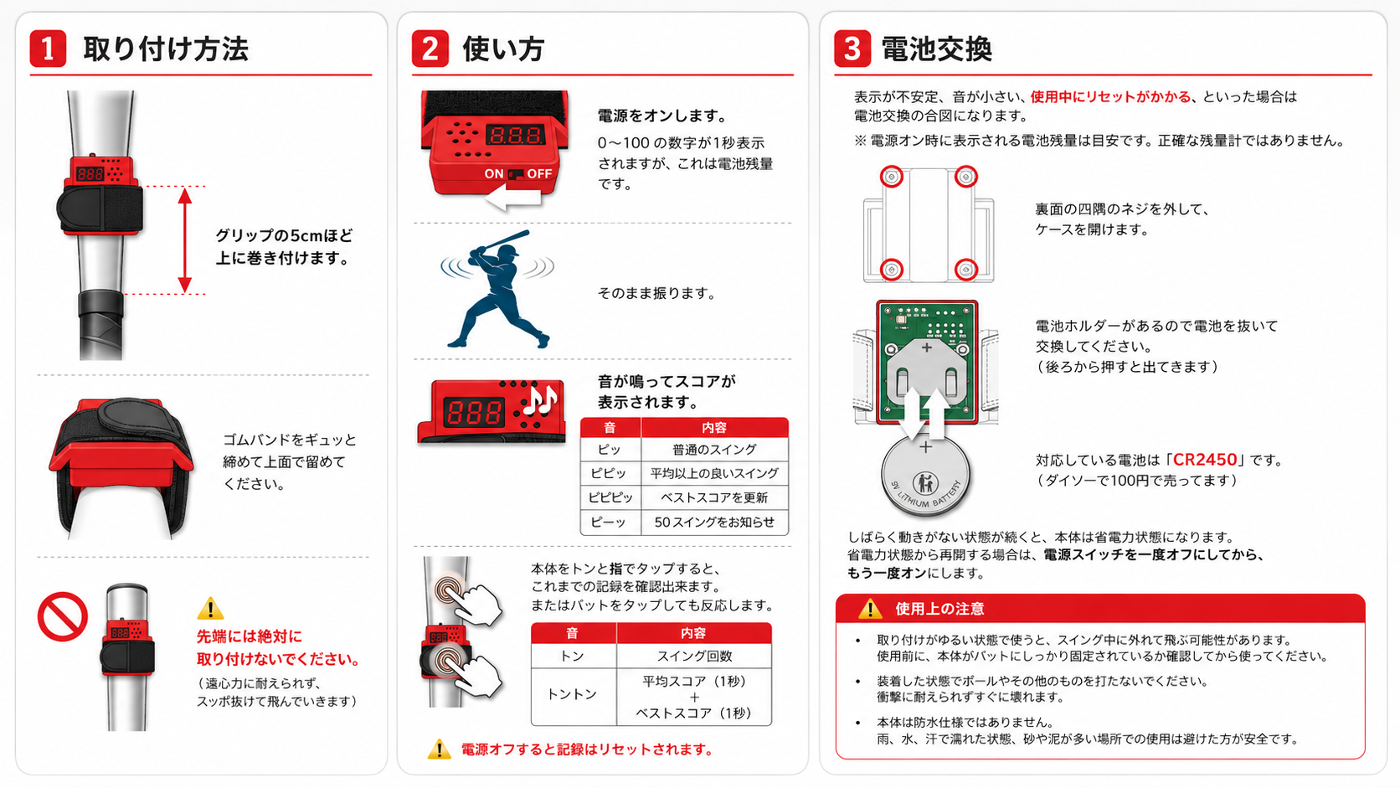
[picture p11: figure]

ON

OFF

しばらく動きがない状態が続くと、本体は省電力状態になります。
再開する場合は、電源スイッチを一度オフにしてから、もう一度オンにします。

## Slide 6

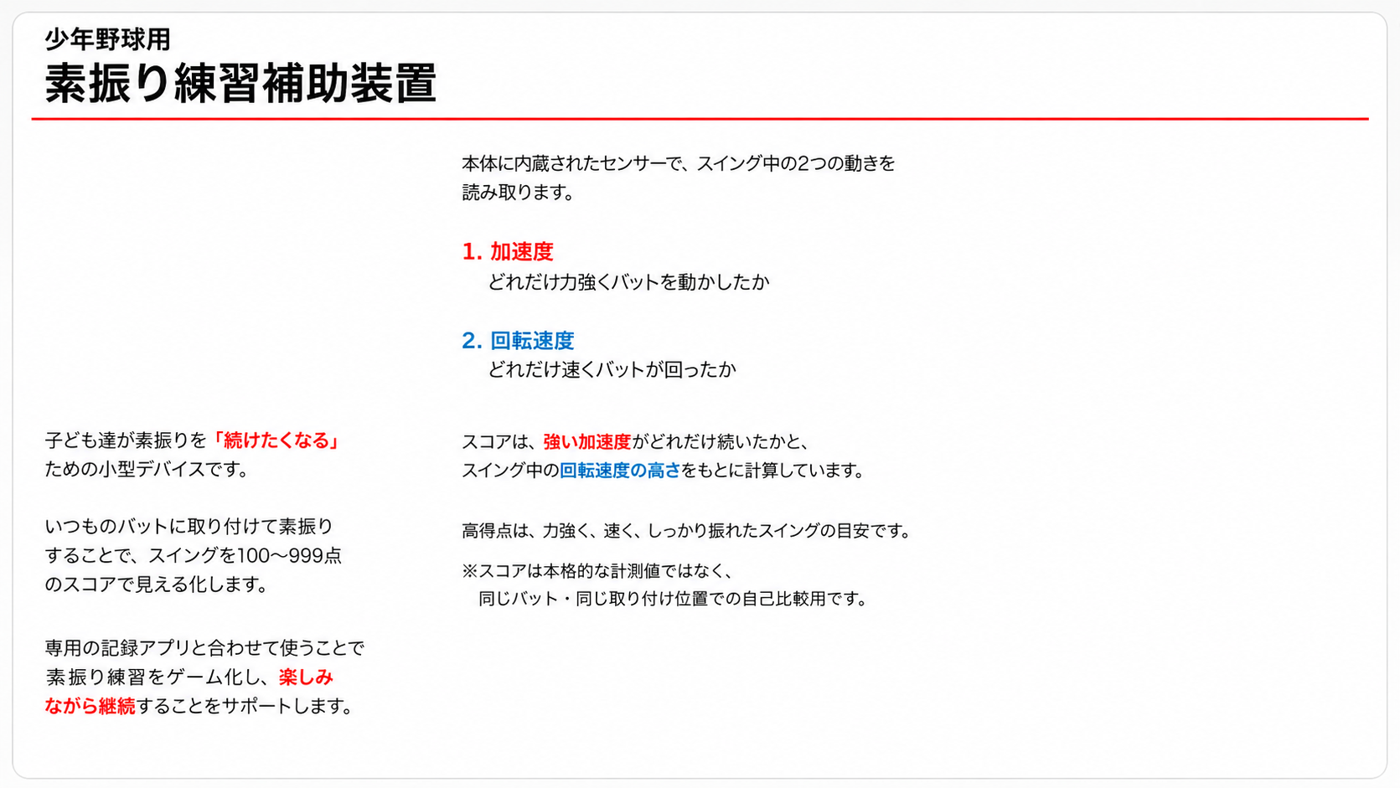
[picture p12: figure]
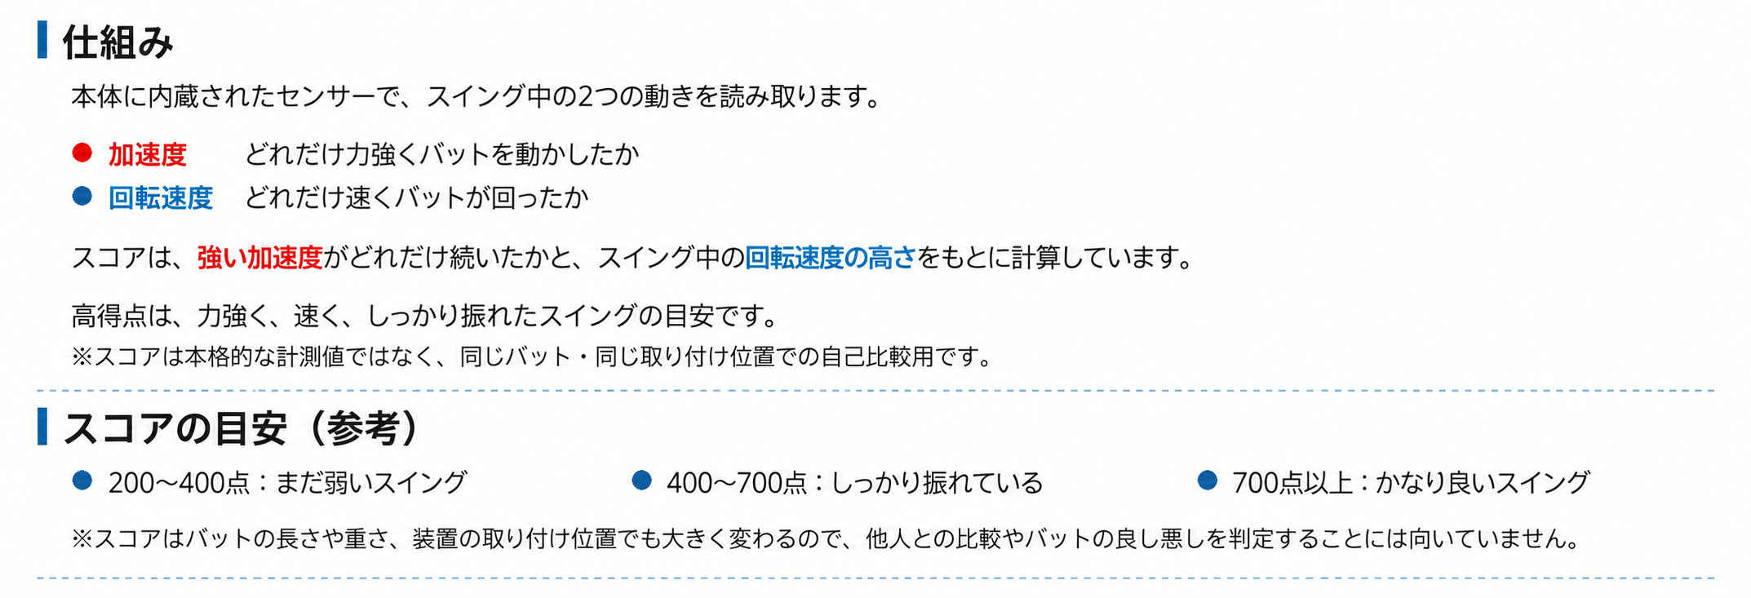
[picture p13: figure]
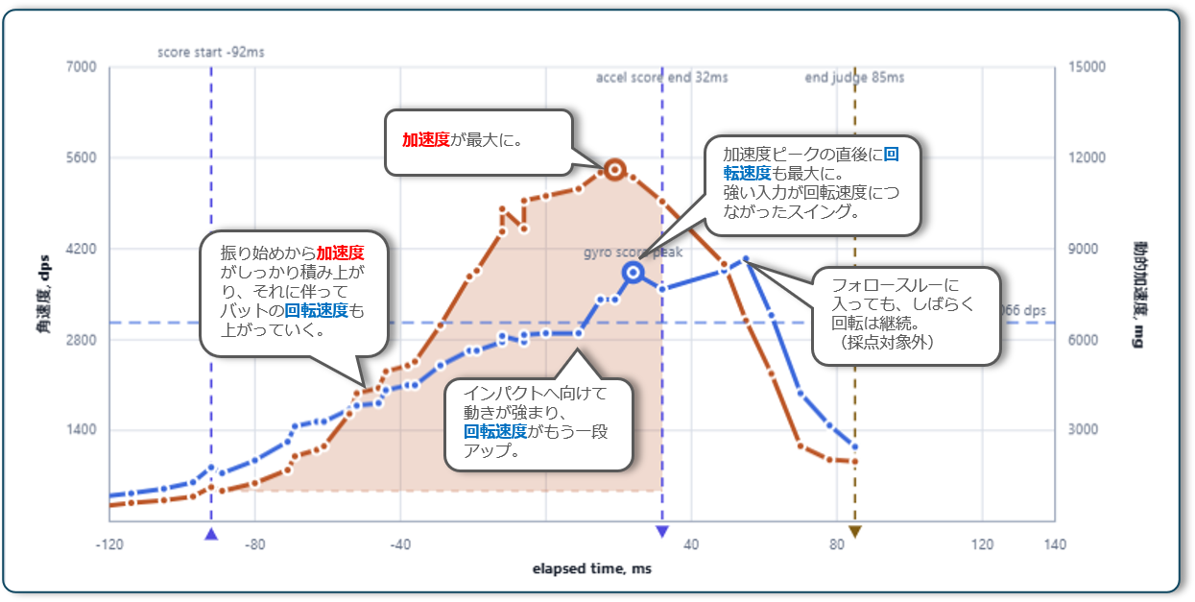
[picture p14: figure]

例）751点のスイング

例）325点のスイング

ピークが低く、立ち上がりも遅い「キレのない」
スイング。

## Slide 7

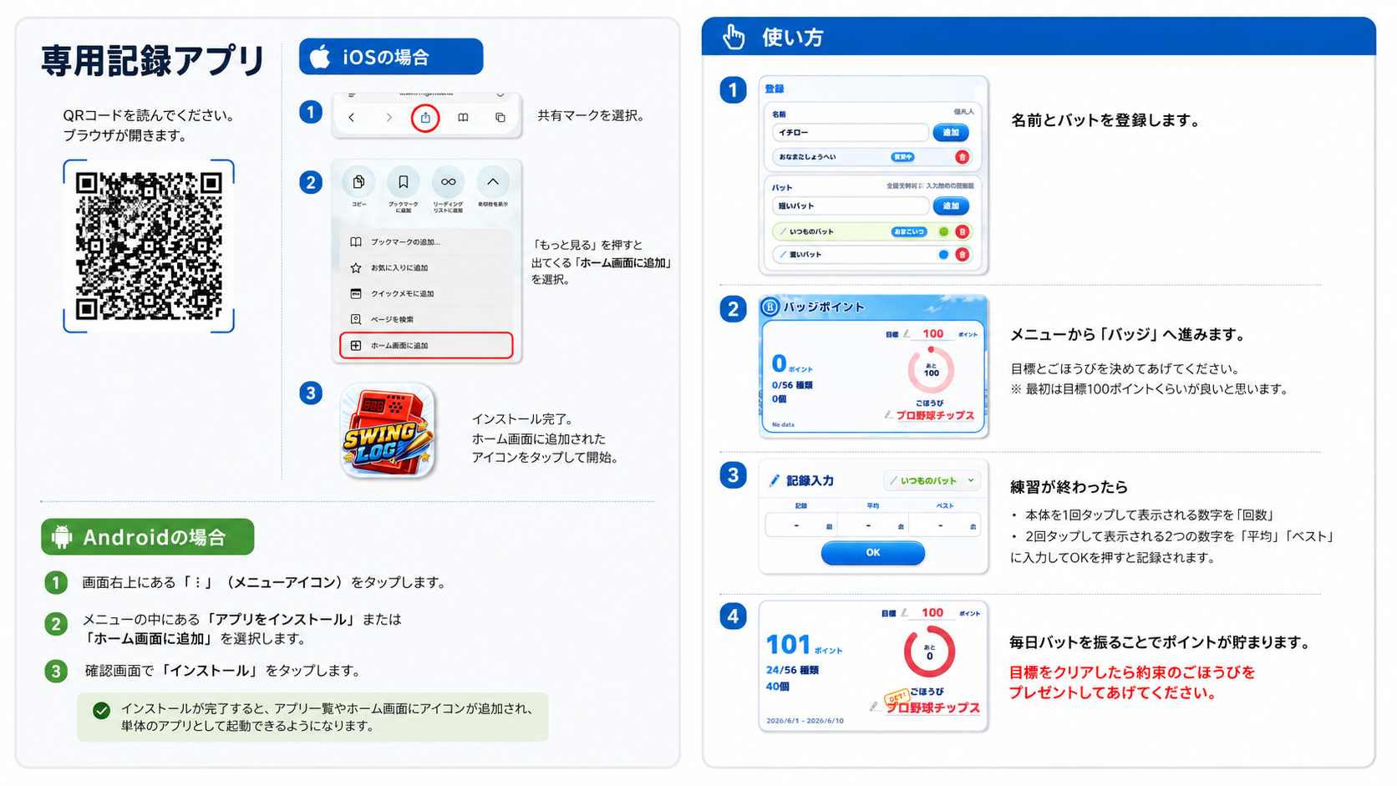
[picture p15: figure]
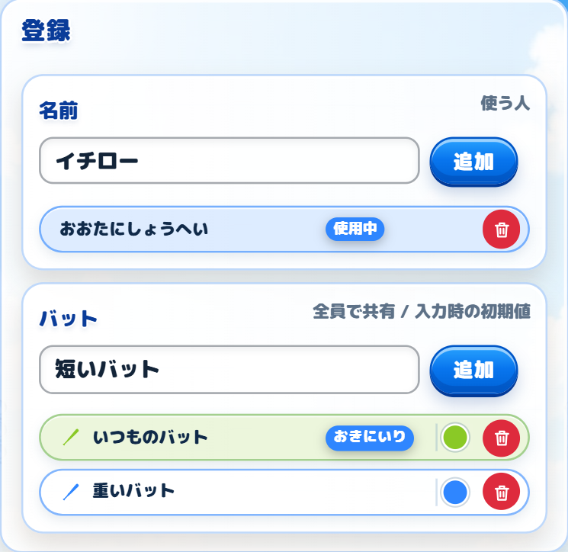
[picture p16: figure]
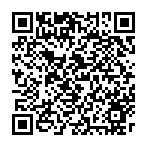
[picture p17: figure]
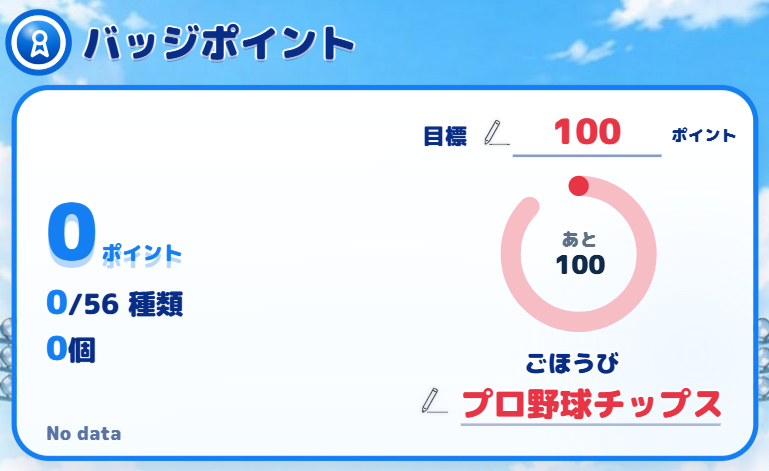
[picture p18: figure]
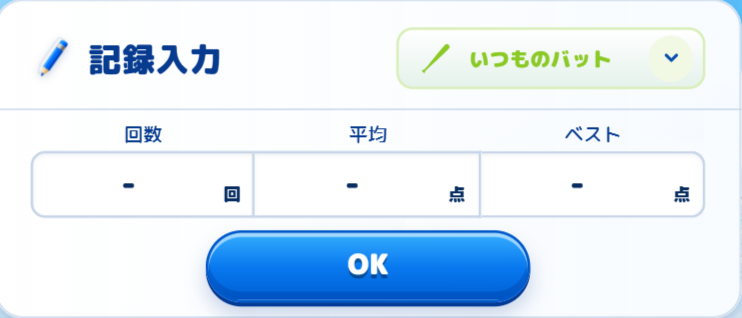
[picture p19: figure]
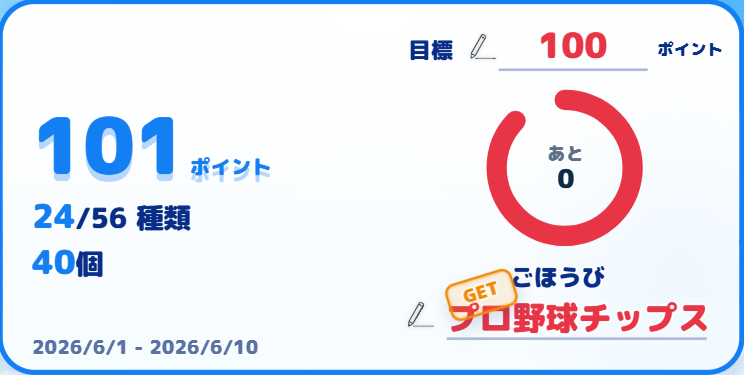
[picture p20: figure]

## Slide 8

専用記録アプリ

QRコードを読んでください。ブラウザが開きます。

iOSの場合

共有マークを選択。

「もっと見る」を押すと出てくる「ホーム画面に追加」を選択。

使い方

名前とバットを登録します。

メニューから「バッジ」へ進みます。

目標とごほうびを決めてあげてください。
※ 最初は目標100ポイントくらいが良いと思います。

練習が終わったら
・　本体を1回タップして表示される数字を「回数」
・　2回タップして表示される2つの数字を「平均」「ベスト」
に入力してOKを押すと記録されます。

毎日バットを振ることでポイントが貯まります。
目標をクリアしたら約束のごほうびをプレゼントしてあげてください。

インストール完了。
ホーム画面に追加されたアイコンをタップして開始。

Androidの場合

1. 画面右上にある 「︙」（メニューアイコン） をタップします。
2. メニューの中にある 「アプリをインストール」 または 「ホーム画面に追加」 を選択します。
3. 確認画面で 「インストール」 をタップします。
インストールが完了すると、アプリ一覧やホーム画面にアイコンが追加され、単体のアプリとして起動できるようになります。

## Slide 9

素振りの強さを採点する装置

本体に内蔵されたセンサーでスイング中の2つの動きを読み取り、100～999点のスコアで採点します。
● 加速度　　どれだけ力強くバットを動かしたか
● 回転速度　どれだけ速くバットが回ったか
強い加速がどれだけ続いたかと、回転速度の高さをもとに計算しています。

スコアの目安（参考）
● ～400点： まだ弱いスイング　● 400～700点： しっかり振れている　● 700点～： かなり良いスイング

例）751点のスイング

例）325点のスイング

⚠️ 注意

- 本格的な計測器ではなく、あくまで玩具です。
- スコアはバットの長さ（重さ）や取り付け位置で大きく変わるので、他人との比較やバットの良し悪しを判断することには向いていません。

毎日の記録を入力することで
- スイング回数
- スコア（平均・ベスト）
- 練習日数
を集計し、実績に応じたポイントを獲得できるゲーム風アプリです。

おまけ： 専用記録アプリ

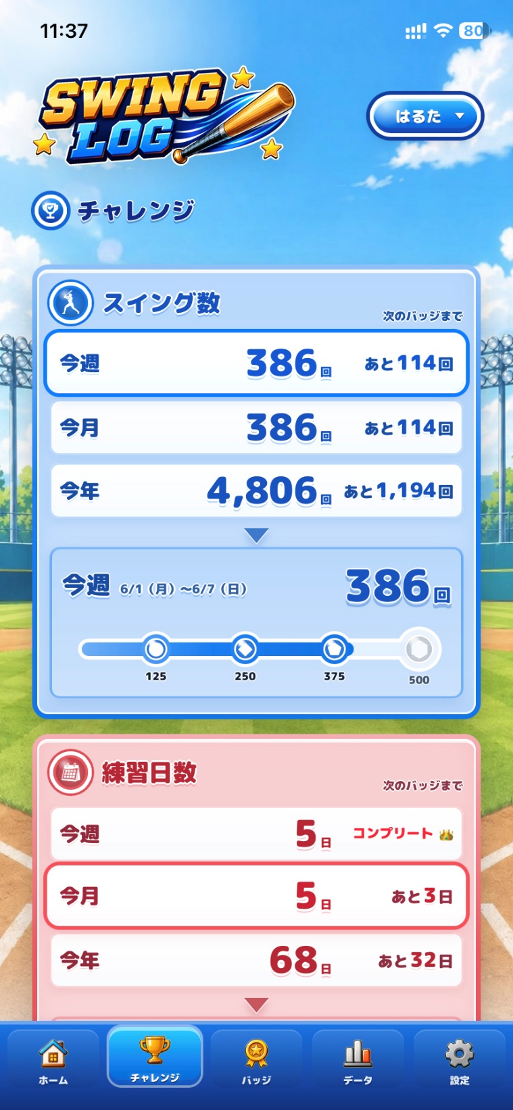
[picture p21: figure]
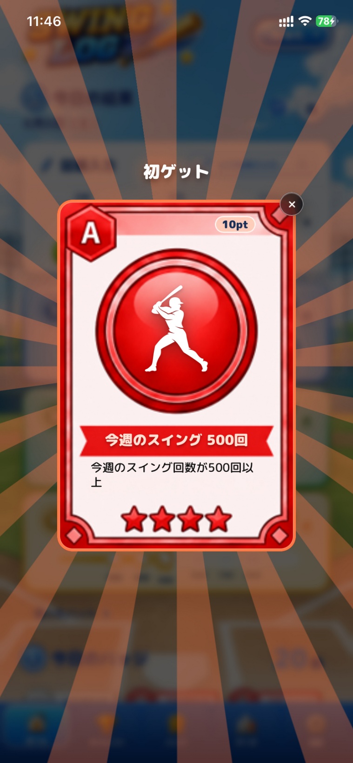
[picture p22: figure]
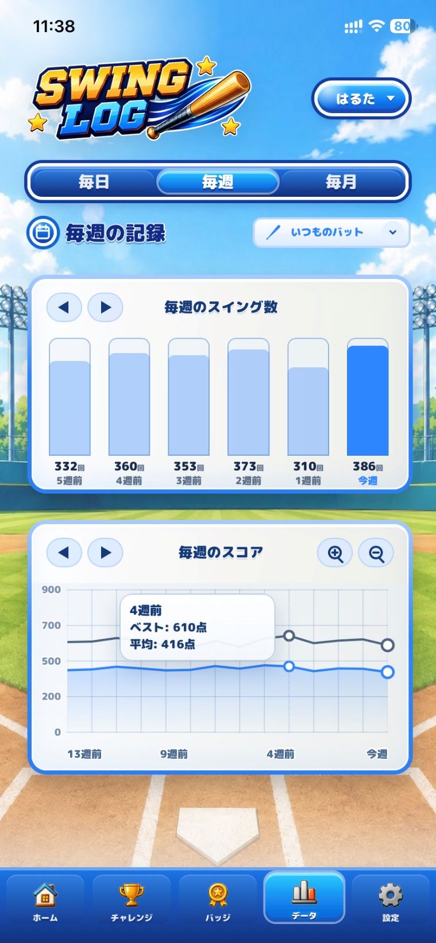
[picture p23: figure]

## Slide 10

取り付け方法

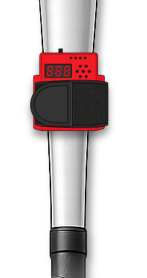
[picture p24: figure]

グリップの5cmほど上に巻き付けます。

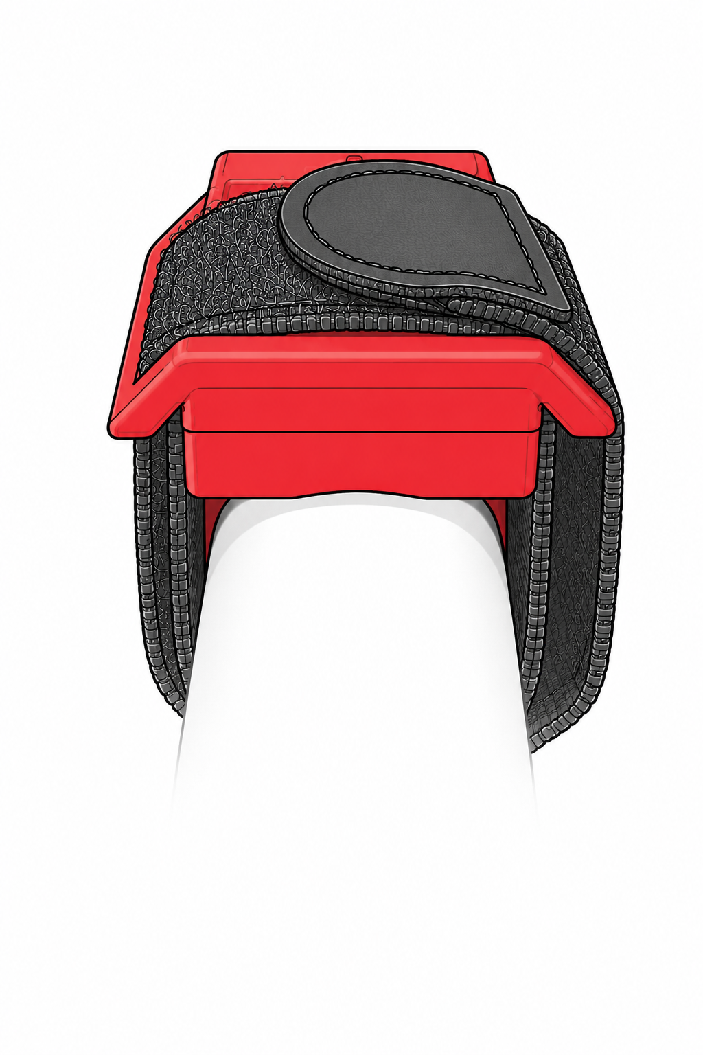
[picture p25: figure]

ゴムバンドをギュッと締めて上面で留めてください。

⚠️先端には絶対に取り付けない。

遠心力に耐えられず、スッポ抜けて飛んでいきます。

1

使い方

2

3

4

ON

OFF

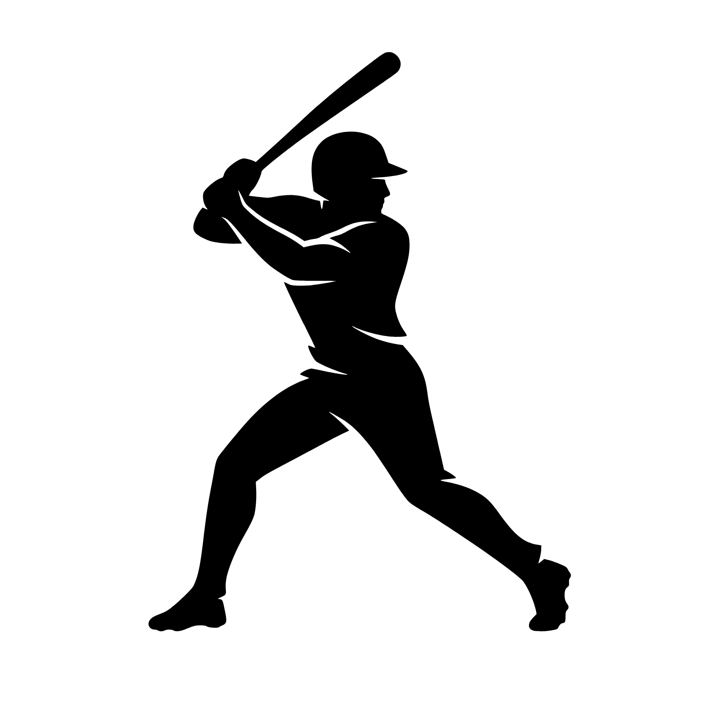
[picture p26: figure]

そのまま振ります。

電源をオンします。
電池残量（～100）が1秒表示されます。

音が鳴ってスコアが
表示されます。

ピッ | 普通のスイング
ピピッ | 平均以上のスイング
ピピピッ | ベストスコアを更新
ピーッ | 50スイングをお知らせ

本体（またはバット）を
指でタップすると、これまでの記録を確認出来ます。

トン | スイング回数
トントン | 平均スコア（1秒） ↓ ベストスコア（1秒）

⚠️電源オフすると記録はリセットされます。

※ しばらく動きがない状態が続くと、本体は省電力状態になります。
再開する場合は、電源スイッチを一度オフにしてから、もう一度オンにします。

⚠️ 使用上の注意

- 取り付けがゆるい状態で使うと、スイング中に外れて飛ぶ可能性があります。 使用前に、本体がバットにしっかり固定されているか確認してから使ってください。
- 装着した状態でボールやその他のものを打たないでください。衝撃に耐えられずすぐに壊れます。
- 本体は防水仕様ではありません。雨、水、汗で濡れた状態、砂や泥が多い場所での使用は避けた方が安全です。

電池交換

表示が不安定、音が小さい、使用中にリセットがかかる、といった場合は電池交換の合図になります。
※ 電源オン時に表示される電池残量は目安です。正確な残量計ではありません。

1

裏面の四隅のネジを外して、ケースを開けます。

2

電池ホルダーがあるので電池を抜いて交換してください。
（後ろから押すと出てきます）

対応している電池は「CR2450」です。
（ダイソーで100円で売ってます）

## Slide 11

専用記録アプリ：インストール方法

QRコードを読んでください。
ブラウザが開きます。

1

共有マークを選択。

「もっと見る」を押して
「ホーム画面に追加」
を選択。

1

1. 画面右上にある 「︙」（メニューアイコン） をタップします。
2. メニューの中にある 「アプリをインストール」 を選択します。
3. 確認画面で 「インストール」 をタップします。

2

2

3

インストール完了。
ホーム画面に追加されたアイコンをタップして開始。

使い方

1

名前とバットを登録します。

メニューから「バッジ」へ進みます。

目標とごほうびを決めてあげてください。
※ 最初は目標100ポイントくらいが良いと思います。

2

3

練習が終わったら
・　本体を1回タップして表示される数字を「回数」
・　2回タップして表示される2つの数字を「平均」「ベスト」
に入力してOKを押すと記録されます。

4

毎日バットを振ることでポイントが貯まります。
目標をクリアしたら約束のごほうびをプレゼントしてあげてください。

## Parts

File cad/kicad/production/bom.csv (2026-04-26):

Designator | Footprint | Quantity | Value | LCSC Part #
BT1 | BAT_3009 | 1 | Keystone 3009
C1 | 1210 | 1 | 47uF
C2 | 0603 | 1 | 10uF
C3, C8 | 0603 | 2 | 10nF
C4, C6, C7 | 0603 | 3 | 100nF
C5 | 0603 | 1 | 1uF
J1, J2, J3, J4, J5, J6, J7, J8 | TestPoint_Pad_D1.5mm | 8 | Pogopin Pad
LS1 | Buzzer_PT86-091940LMR | 1 | PT86-091940LMR
Q1, Q2, Q3 | SOT95P280X125-3N | 3 | AO3400A
R1, R2 | 0603 | 2 | 47
R10, R11, R12, R5, R6, R8, R9 | 0603 | 7 | 470
R3, R4, R7 | 0603 | 3 | 100K
SW1 | MSS22D18 | 1 | SW_SPDT
U1 | QFN_LSM6DSV80XTR_STM | 1 | LSM6DSV80XTR
U2 | SOIC-20W_7.5x12.8mm_P1.27mm | 1 | ATtiny3226-S
U3 | OSL30251 | 1 | OSL30251

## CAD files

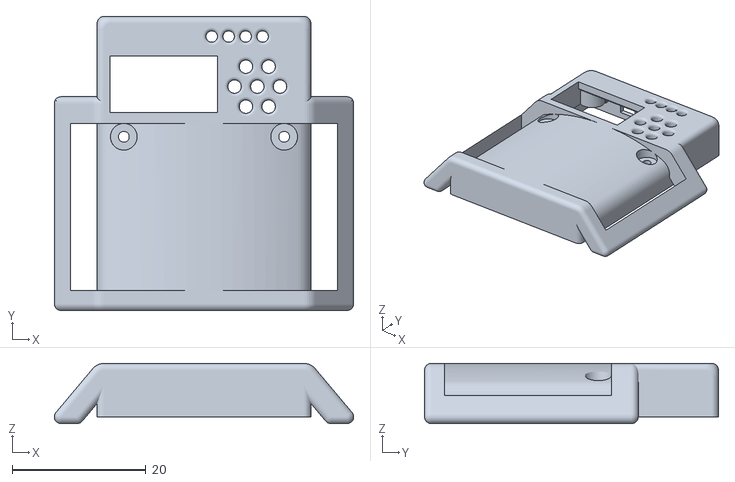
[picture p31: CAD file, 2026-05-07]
cad/fusion/Top.stl
44.8 x 44.0 x 9.00

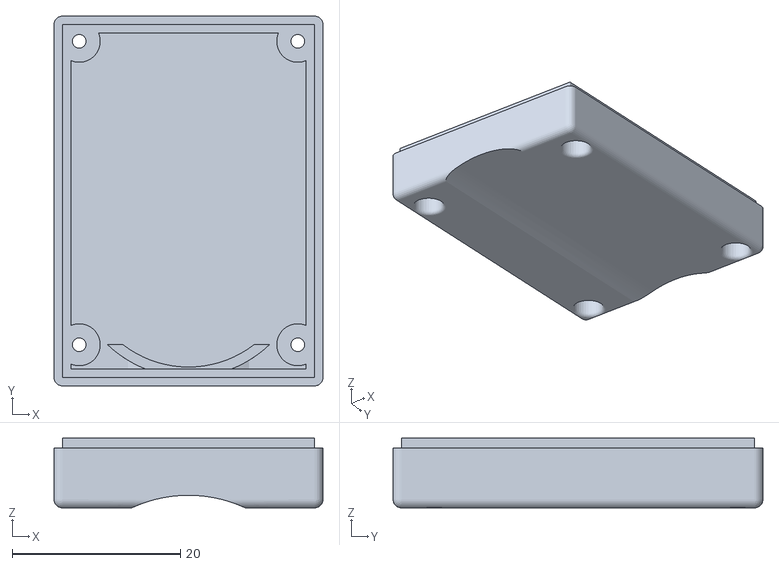
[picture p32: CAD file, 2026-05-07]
cad/fusion/Bottom.stl
32.0 x 44.0 x 8.30

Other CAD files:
cad/fusion/Case_Wide.f3d

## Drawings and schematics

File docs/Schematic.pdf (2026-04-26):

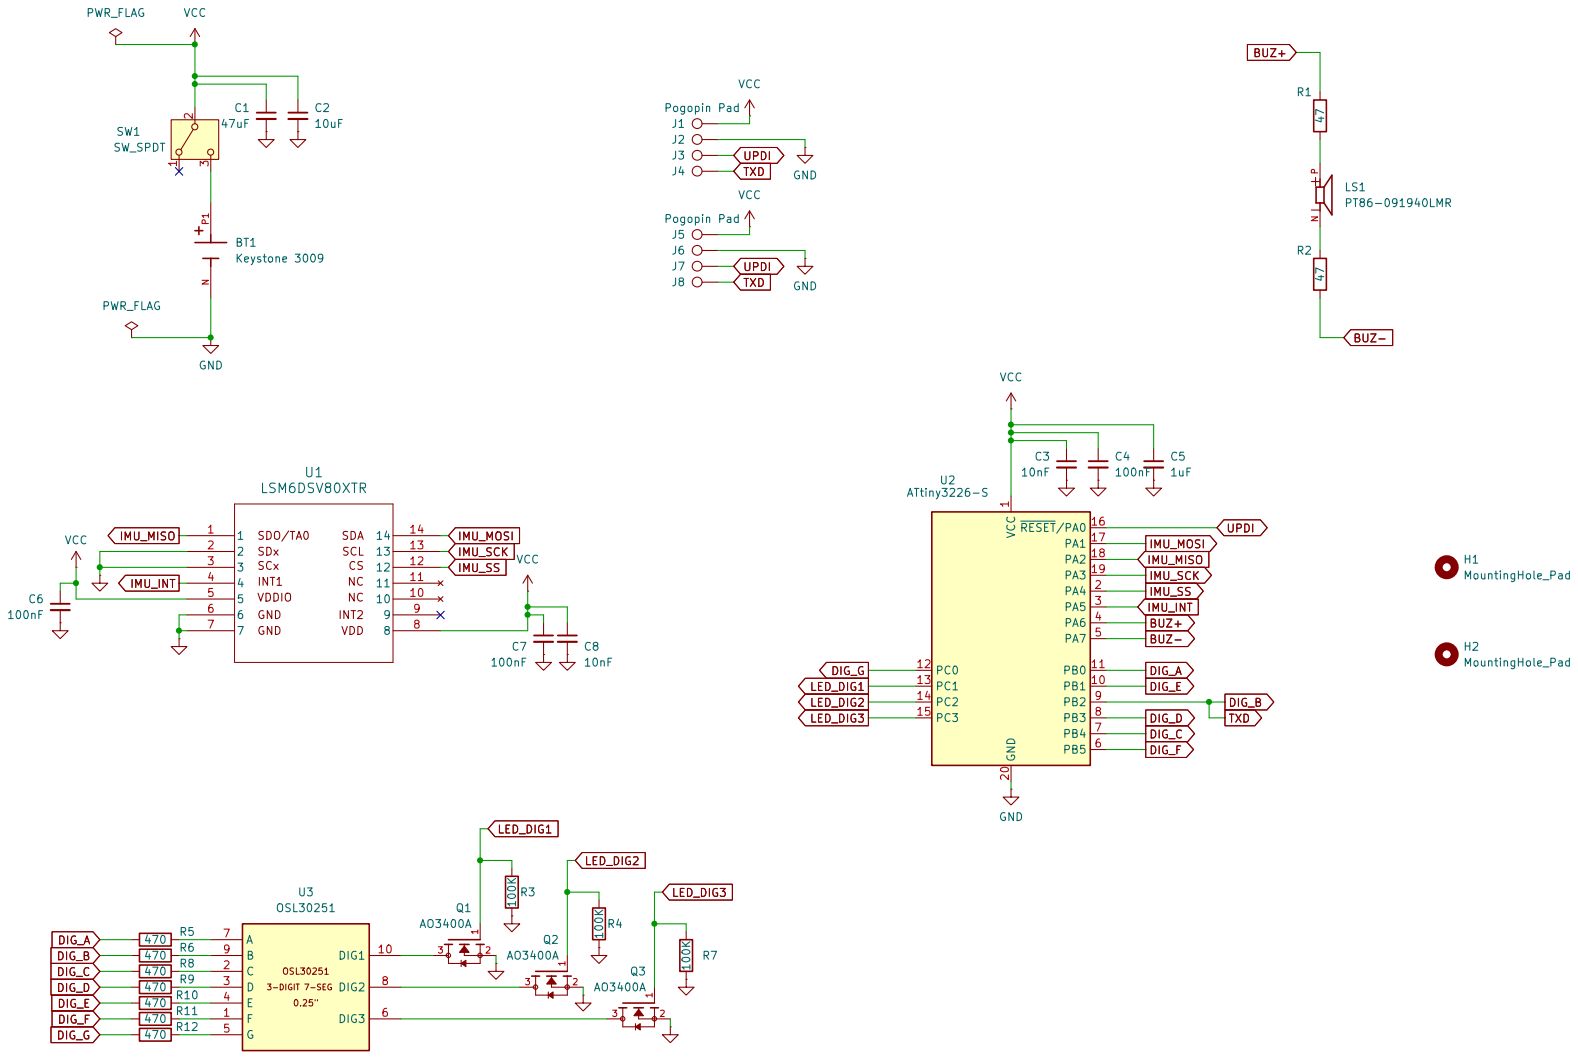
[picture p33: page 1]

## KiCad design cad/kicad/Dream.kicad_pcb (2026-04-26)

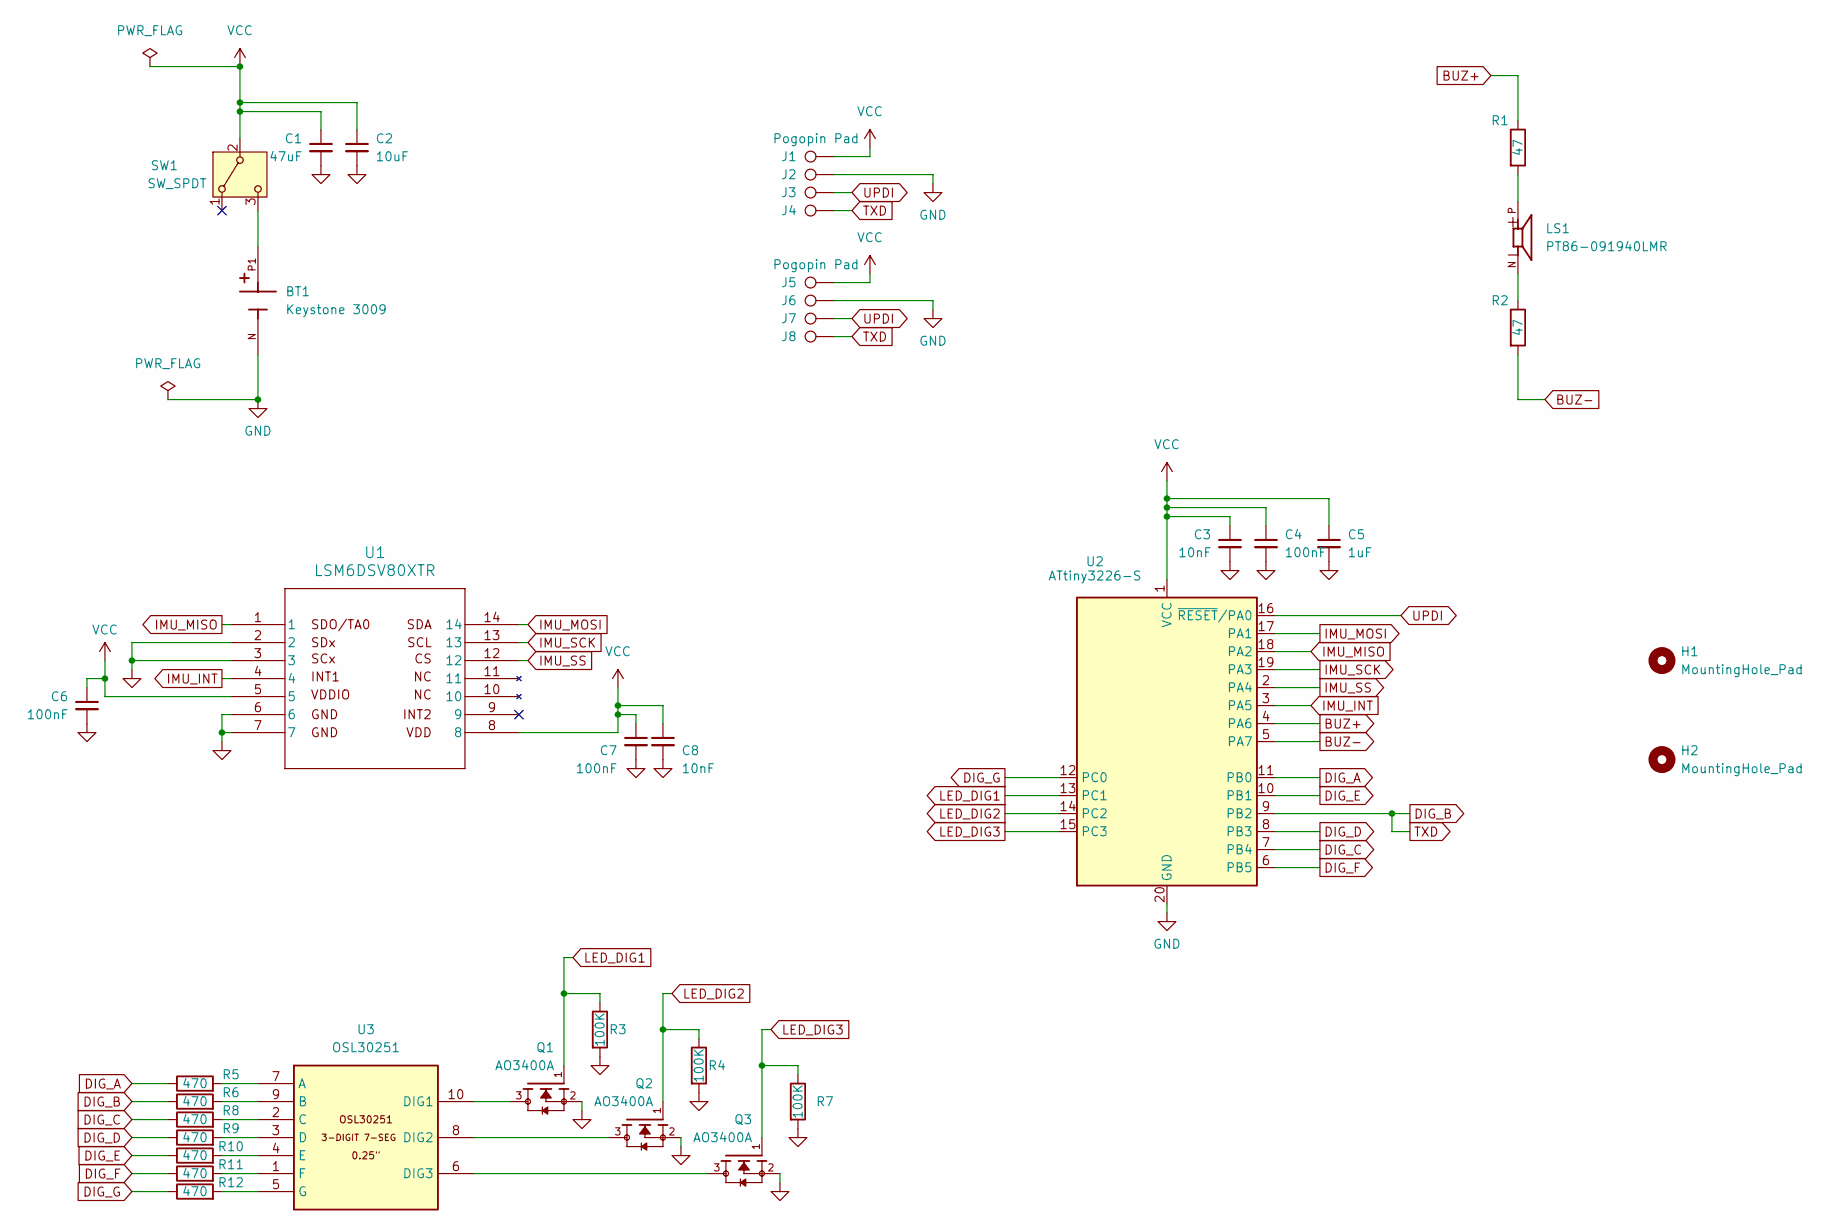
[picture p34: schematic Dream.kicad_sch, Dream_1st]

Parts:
BT1: Keystone 3009; BAT_3009; PARTREV G; DigiKey_Part_Number 36-1052CT-ND
C1: 47uF; C_1210_3225Metric_Pad1.33x2.70mm_HandSolder
C2: 10uF; C_0603_1608Metric_Pad1.08x0.95mm_HandSolder
C3, C8: 10nF; C_0603_1608Metric_Pad1.08x0.95mm_HandSolder
C4, C6, C7: 100nF; C_0603_1608Metric_Pad1.08x0.95mm_HandSolder
C5: 1uF; C_0603_1608Metric_Pad1.08x0.95mm_HandSolder
H1, H2: MountingHole_Pad; MountingHole_2.2mm_M2_Pad_TopOnly
J1, J2, J3, J4, J5, J6, J7, J8: Pogopin Pad; TestPoint_Pad_D1.5mm
LS1: PT86-091940LMR; Buzzer_PT86-091940LMR; PARTREV December 26, 2017; DigiKey_Part_Number 490-4698-1-ND
Q1, Q2, Q3: AO3400A; SOT95P280X125-3N; PARTREV L; DigiKey_Part_Number 785-1000-1-ND
R1, R2: 47; R_0603_1608Metric_Pad0.98x0.95mm_HandSolder
R3, R4, R7: 100K; R_0603_1608Metric_Pad0.98x0.95mm_HandSolder
R5, R6, R8, R9, R10, R11, R12: 470; R_0603_1608Metric_Pad0.98x0.95mm_HandSolder
SW1: SW_SPDT; MSS22D18
U1: LSM6DSV80XTR; QFN_LSM6DSV80XTR_STM
U2: ATtiny3226-S; SOIC-20W_7.5x12.8mm_P1.27mm
U3: OSL30251

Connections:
BUZ+: R1.1, U2.4 (PA6)
BUZ-: R2.2, U2.5 (PA7)
DIG_A: R5.1, U2.11 (PB0)
DIG_B: J4.1 (1_1), J8.1 (1_1), R6.1, U2.9 (PB2)
DIG_C: R8.1, U2.7 (PB4)
DIG_D: R9.1, U2.8 (PB3)
DIG_E: R10.1, U2.10 (PB1)
DIG_F: R11.1, U2.6 (PB5)
DIG_G: R12.1, U2.12 (PC0)
GND: BT1.N, C1.2, C2.2, C3.2, C4.2, C5.2, C6.2, C7.2, C8.2, J2.1 (1_1), J6.1 (1_1), Q1.2, Q2.2, Q3.2, R3.2, R4.2, R7.2, U1.2, U1.3, U1.6, U1.7, U2.20 (GND)
IMU_INT: U1.4, U2.3 (PA5)
IMU_MISO: U1.1, U2.18 (PA2)
IMU_MOSI: U1.14, U2.17 (PA1)
IMU_SCK: U1.13, U2.19 (PA3)
IMU_SS: U1.12, U2.2 (PA4)
LED_DIG1: Q1.1, R3.1, U2.13 (PC1)
LED_DIG2: Q2.1, R4.1, U2.14 (PC2)
LED_DIG3: Q3.1, R7.1, U2.15 (PC3)
unnamed: LS1.N, R2.1
unnamed: LS1.P, R1.2
unnamed: BT1.P1, BT1.P2, SW1.3 (C)
unnamed: R5.2, U3.7 (A)
unnamed: R6.2, U3.9 (B)
unnamed: R8.2, U3.2 (C)
unnamed: R9.2, U3.3 (D)
unnamed: Q1.3, U3.10 (DIG1)
unnamed: Q2.3, U3.8 (DIG2)
unnamed: Q3.3, U3.6 (DIG3)
unnamed: R10.2, U3.4 (E)
unnamed: R11.2, U3.1 (F)
unnamed: R12.2, U3.5 (G)
UPDI: J3.1 (1_1), J7.1 (1_1), U2.16 (~RESET/PA0)
VCC: C1.1, C2.1, C3.1, C4.1, C5.1, C6.1, C7.1, C8.1, J1.1 (1_1), J5.1 (1_1), SW1.2 (B), U1.5, U1.8, U2.1 (VCC)

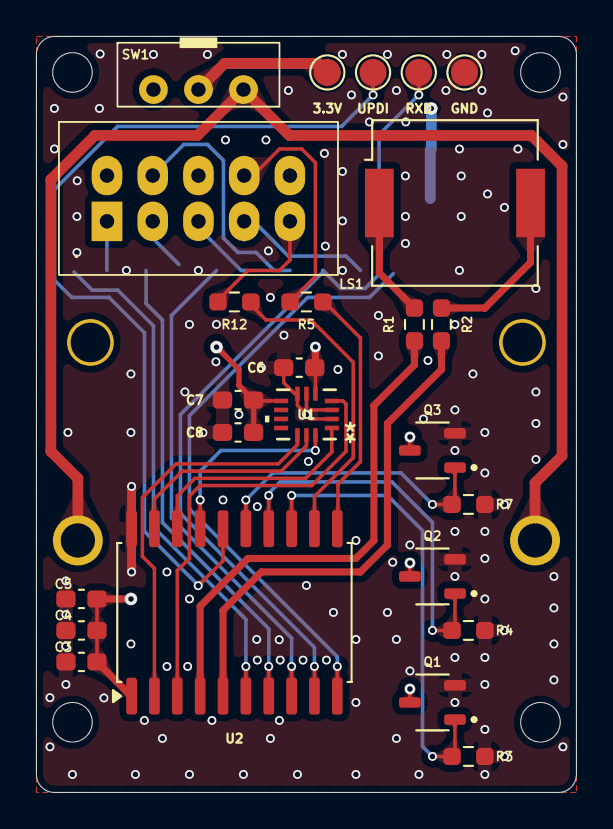
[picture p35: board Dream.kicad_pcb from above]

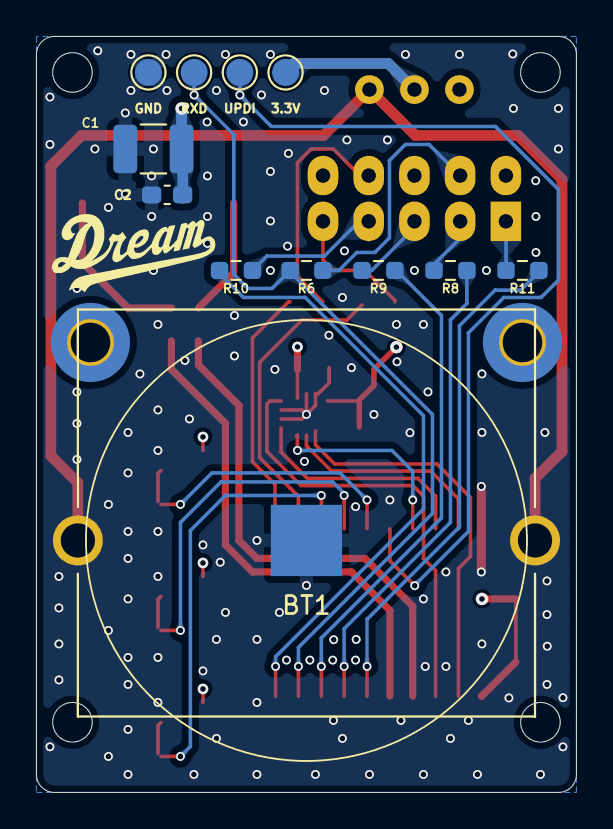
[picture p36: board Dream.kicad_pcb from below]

Board: 4 copper layers, 30.0 x 42.0 mm, 39 parts (14 on the bottom side), 33 nets.

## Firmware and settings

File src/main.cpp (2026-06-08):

#include <Arduino.h>
#include <EEPROM.h>
#include <stddef.h>
#include <avr/sleep.h>
#include <megaTinyCore.h>

#include "buzzer.h"
#include "display.h"
#include "imu.h"
#include "tap.h"

namespace {

enum class RunMode : uint8_t {
  Calibrate,
  Monitor,
  Capturing,
  ShowingScore,
  Cooldown,
};

enum class TapStatsStage : uint8_t {
  None,
  Average,
  Best,
};

const uint16_t kGyroCalibrationWindowMs = 1000;
const uint16_t kCaptureMaxMs = 900;
const uint16_t kCaptureMinMs = 80;
const uint16_t kMinAcceptedSwingDurationMs = 160;
const uint16_t kShortSwingDurationMs = 80;
const uint16_t kCaptureEndDropPct = 70;
const uint16_t kCaptureDiscardCooldownMs = 120;
const uint16_t kTapMuteAfterScoreMs = 250;
const uint16_t kTapMuteAfterStartupMs = 1000;
const uint16_t kTapAcceptMuteMs = 80;
const uint8_t kTapPollMs = 50;
const uint8_t kIntStallClearMs = 10;
const uint16_t kSingleTapConfirmMs = 300;
const uint16_t kDoubleTapMinGapMs = 30;
const uint16_t kCaptureStartStrength = 2400;
const uint16_t kCaptureStartGyroRaw = 900;
const uint16_t kCaptureRestartStrength = 1800;
const uint16_t kPreCaptureQuietMs = 70;
const uint8_t kMinSwingEvidence = 6;
const uint16_t kMinDisplayScore = 100;
const uint16_t kScoreDisplayMs = 2000;
const uint16_t kTapStatsDisplayMs = 1000;
const uint16_t kTapDisplayMs = 1400;
const uint8_t kMilestoneSwingInterval = 50;
const uint16_t kBaselineTrackDeltaMg = 120;
const uint16_t kBatteryFullMv = 3000;
const uint16_t kBatteryEmptyMv = 2600;
const uint32_t kAutoSleepIdleMs = 300000UL;

const uint16_t kCaptureStartAccelMg = 1800;
const uint16_t kActivityStrengthThreshold = 650;

const uint16_t kNoTimeMs = 65535;
const uint16_t kAccelRiseStartMg = 700;
const uint16_t kAccelTrendNoiseMg = 140;
const uint8_t kAccelTrendFallSamples = 2;
const uint16_t kGyroRiseThresholdRaw = 900;
const uint16_t kGyroRiseTooFastMs = 15;
const uint16_t kGyroRiseGoodMs = 35;
const uint16_t kGyroMdpsPerLsb = 140;
const uint16_t kGyroPeakFullDps = 7000;
const uint16_t kGyroPeakScoreMax = 500;
const uint16_t kSwingAccelAreaScoreOffsetMg = 1000;
const uint32_t kSwingAccelAreaFullMgMs = 800000UL;
const uint16_t kSwingAccelAreaScoreMax = 500;
const uint16_t kInternalScoreMax = 999;
const uint32_t kBestTelemetryMagic = 0x42535747UL;  // "BSWG"
const uint8_t kBestTelemetryVersion = 20;
const uint8_t kCaptureLogSampleCapacity = 96;
const uint8_t kPreCaptureLogSampleCapacity = 24;
const uint16_t kPreCaptureTelemetryMs = 300;
const uint8_t kTelemetryEepromBytesPerService = 1;
const uint8_t kScoreAccelDropPct = 10;
const uint16_t kScoreAccelDropMinMg = 1000;
struct BestSwingSample {
  int16_t elapsedMs;
  uint16_t gyroRaw;
  uint16_t accelMg;
} __attribute__((packed));

struct PreCaptureSample {
  uint32_t sampledMs;
  uint16_t gyroRaw;
  uint16_t accelMg;
};

struct ScoreWindow {
  bool hasSamples;
  int16_t startMs;
  int16_t accelPeakMs;
  int16_t endMs;
  uint16_t accelPeakMg;
};

struct BestSwingTelemetryHeader {
  uint32_t magic;
  uint8_t version;
  uint8_t checksum;
  uint8_t sampleCount;
  uint16_t sampleTotal;
  uint16_t score;
  uint16_t swingNumber;
  uint16_t averageBefore;
  uint16_t swingDurationMs;
  uint16_t endDecisionMs;
  int16_t scoreStartMs;
  int16_t scoreEndMs;
  int16_t accelPeakMs;
  uint8_t preSampleCount;
  uint8_t preRingCount;
  uint8_t recentSampleCount;
  uint16_t recentMaxAgeMs;
  uint32_t accelAreaMgMs;
  uint16_t gyroScore;
  uint16_t accelScore;
} __attribute__((packed));

RunMode runMode = RunMode::Calibrate;
uint32_t calibrationUntilMs = 0;
uint32_t swingStartedMs = 0;
uint32_t scoreUntilMs = 0;
uint32_t tapStatsUntilMs = 0;
uint32_t cooldownUntilMs = 0;
uint32_t tapMutedUntilMs = 0;
uint32_t lastTapPollMs = 0;
uint32_t singleTapConfirmAtMs = 0;
uint32_t lastSingleTapEventMs = 0;
uint32_t motionCandidateStartedMs = 0;
uint32_t motionCandidateLastMs = 0;
uint32_t lastActivityMs = 0;
uint32_t lastImuInterruptMs = 0;

int32_t gyroXSum = 0;
int32_t gyroYSum = 0;
int32_t gyroZSum = 0;
uint32_t accelSumMg = 0;
uint16_t calibrationSamples = 0;
int16_t gyroBaselineX = 0;
int16_t gyroBaselineY = 0;
int16_t gyroBaselineZ = 0;
uint16_t accelBaselineMg = 1000;

uint16_t gyroPeakRaw = 0;
uint16_t accelPeakMg = 0;
uint16_t accelRiseMs = 0;
uint16_t maxAccelRiseMs = 0;
uint16_t accelTrendPeakMg = 0;
uint16_t firstGyroStrongTimeMs = kNoTimeMs;
uint32_t swingAccelAreaMgMs = 0;
uint8_t accelTrendFallCount = 0;
uint16_t bestScore = 0;
uint16_t swingCount = 0;
uint32_t scoreTotal = 0;
uint16_t scoreSampleCount = 0;
uint32_t lastMeasureSampleMs = 0;
uint32_t lastSwingMotionMs = 0;
uint32_t swingStartDecisionMs = 0;
uint16_t swingEndDecisionMs = 0;
uint8_t importedPreCaptureSampleCount = 0;
uint8_t preCaptureRingCountAtStart = 0;
uint8_t recentSampleCountAtStart = 0;
uint16_t recentSampleMaxAgeMsAtStart = 0;
uint16_t capturePeakStrength = 0;
bool swingStarted = false;
TapStatsStage tapStatsStage = TapStatsStage::None;
BestSwingSample captureSamples[kCaptureLogSampleCapacity] = {};
PreCaptureSample preCaptureSamples[kPreCaptureLogSampleCapacity] = {};
BestSwingSample telemetrySamplesToWrite[kCaptureLogSampleCapacity] = {};
uint8_t telemetrySampleSelected[kCaptureLogSampleCapacity] = {};
BestSwingTelemetryHeader telemetryHeaderToWrite = {};
uint16_t telemetryWriteIndex = 0;
uint16_t telemetryWriteByteCount = 0;
uint16_t telemetryWriteSampleBytes = 0;
bool telemetryWritePending = false;
uint8_t captureSampleWriteIndex = 0;
uint8_t captureSampleCount = 0;
uint16_t captureSampleTotal = 0;
uint8_t preCaptureSampleWriteIndex = 0;
uint8_t preCaptureSampleCount = 0;

void enterFinalSleep() {
  Display::off();
  Buzzer::off();
  Imu::enterSleepMode();

  set_sleep_mode(SLEEP_MODE_PWR_DOWN);
  sleep_enable();
  noInterrupts();
  for (;;) {
    sleep_cpu();
  }
}

void enterIdleSleep() {
  set_sleep_mode(SLEEP_MODE_IDLE);
  sleep_enable();
  noInterrupts();
  interrupts();
  sleep_cpu();
  sleep_disable();
}

bool isIdleTimedOut(uint32_t nowMs) {
  return static_cast<int32_t>(nowMs - (lastActivityMs + kAutoSleepIdleMs)) >= 0;
}

void clearPendingSingleTap() {
  singleTapConfirmAtMs = 0;
  lastSingleTapEventMs = 0;
}

void clearPendingTapEvents() {
  singleTapConfirmAtMs = 0;
  lastSingleTapEventMs = 0;
}

void clearTapStatsDisplay() {
  tapStatsStage = TapStatsStage::None;
  tapStatsUntilMs = 0;
}

bool isTapPollDue(uint32_t nowMs) {
  return static_cast<uint16_t>(nowMs - lastTapPollMs) >= kTapPollMs;
}

void queueSingleTap(uint32_t nowMs) {
  singleTapConfirmAtMs = nowMs + kSingleTapConfirmMs;
}

bool isSingleTapConfirmed(uint32_t nowMs) {
  return singleTapConfirmAtMs != 0 &&
         static_cast<int32_t>(nowMs - singleTapConfirmAtMs) >= 0;
}

uint16_t averageScoreOrZero() {
  if (scoreSampleCount == 0) {
    return 0;
  }
  return static_cast<uint16_t>(
      (scoreTotal + (scoreSampleCount / 2UL)) / scoreSampleCount);
}

void showAverageThenBest(uint32_t nowMs) {
  clearPendingTapEvents();
  lastActivityMs = nowMs;
  tapStatsStage = TapStatsStage::Average;
  tapStatsUntilMs = nowMs + kTapStatsDisplayMs;
  tapMutedUntilMs = nowMs + (kTapStatsDisplayMs * 2U) + kTapAcceptMuteMs;
  scoreUntilMs = nowMs + (kTapStatsDisplayMs * 2U);
  Display::showNumber(averageScoreOrZero(), nowMs, kTapStatsDisplayMs);
  runMode = RunMode::ShowingScore;
}

void updateTapStatsDisplay(uint32_t nowMs) {
  if (tapStatsStage == TapStatsStage::Average &&
      static_cast<int32_t>(nowMs - tapStatsUntilMs) >= 0) {
    tapStatsStage = TapStatsStage::Best;
    tapStatsUntilMs = nowMs + kTapStatsDisplayMs;
    Display::showNumber(bestScore, nowMs, kTapStatsDisplayMs);
    return;
  }

  if (tapStatsStage == TapStatsStage::Best &&
      static_cast<int32_t>(nowMs - tapStatsUntilMs) >= 0) {
    clearTapStatsDisplay();
  }
}

void updateDisplayService() {
  const uint32_t nowMs = millis();
  updateTapStatsDisplay(nowMs);
  Display::update(nowMs);
}

void showSwingCount(uint32_t nowMs) {
  clearPendingTapEvents();
  clearTapStatsDisplay();
  lastActivityMs = nowMs;
  Display::showNumber(swingCount, nowMs, kTapDisplayMs);
  scoreUntilMs = nowMs + kTapDisplayMs;
  tapMutedUntilMs = scoreUntilMs + kTapAcceptMuteMs;
  runMode = RunMode::ShowingScore;
}

bool isInterruptStalled(uint32_t nowMs) {
  return static_cast<uint16_t>(nowMs - lastImuInterruptMs) >= kIntStallClearMs;
}

uint32_t squareInt16(int16_t value) {
  const int32_t wideValue = value;
  return static_cast<uint32_t>(wideValue * wideValue);
}

uint16_t isqrt32(uint32_t value) {
  uint32_t bit = 1UL << 30;
  uint32_t result = 0;

  while (bit > value) {
    bit >>= 2;
  }

  while (bit != 0) {
    if (value >= result + bit) {
      value -= result + bit;
      result = (result >> 1) + bit;
    } else {
      result >>= 1;
    }
    bit >>= 2;
  }

  return static_cast<uint16_t>(result);
}

uint16_t magnitudeRaw(int16_t x, int16_t y, int16_t z) {
  return isqrt32(squareInt16(x) + squareInt16(y) + squareInt16(z));
}

uint16_t absDiff16(uint16_t a, uint16_t b) {
  return a > b ? a - b : b - a;
}

uint16_t saturateToUint16(uint32_t value) {
  return value > 65535 ? 65535 : static_cast<uint16_t>(value);
}

uint16_t scoreAccelDropThresholdMg(uint16_t accelPeakMg) {
  const uint16_t pctThreshold =
      static_cast<uint16_t>(
          (static_cast<uint32_t>(accelPeakMg) * kScoreAccelDropPct) / 100UL);
  return pctThreshold > kScoreAccelDropMinMg
             ? pctThreshold
             : kScoreAccelDropMinMg;
}

uint16_t gyroRawToDps(uint16_t gyroRaw) {
  return static_cast<uint16_t>(
      (static_cast<uint32_t>(gyroRaw) * kGyroMdpsPerLsb) / 1000UL);
}

uint8_t bestTelemetrySampleCapacity() {
  if (EEPROM.length() <= sizeof(BestSwingTelemetryHeader)) {
    return 0;
  }
  const size_t available = EEPROM.length() - sizeof(BestSwingTelemetryHeader);
  const size_t capacity = available / sizeof(BestSwingSample);
  return capacity > 255 ? 255 : static_cast<uint8_t>(capacity);
}

uint8_t checksumStep(uint8_t checksum, uint8_t value) {
  checksum ^= value;
  return static_cast<uint8_t>((checksum << 1) | (checksum >> 7));
}

uint8_t bestTelemetryChecksumFromEeprom(uint8_t sampleCount) {
  uint8_t checksum = 0xA5;
  const size_t byteCount =
      sizeof(BestSwingTelemetryHeader) +
      (static_cast<size_t>(sampleCount) * sizeof(BestSwingSample));
  for (size_t i = 0; i < byteCount; ++i) {
    const uint8_t value =
        i == offsetof(BestSwingTelemetryHeader, checksum)
            ? 0
            : EEPROM.read(static_cast<int>(i));
    checksum = checksumStep(checksum, value);
  }
  return checksum;
}

uint8_t bestTelemetryChecksumForWrite(
    const BestSwingTelemetryHeader& header,
    const BestSwingSample* samples) {
  uint8_t checksum = 0xA5;
  const uint8_t* headerBytes = reinterpret_cast<const uint8_t*>(&header);
  for (size_t i = 0; i < sizeof(BestSwingTelemetryHeader); ++i) {
    const uint8_t value =
        i == offsetof(BestSwingTelemetryHeader, checksum) ? 0 : headerBytes[i];
    checksum = checksumStep(checksum, value);
  }
  const uint8_t* sampleBytes = reinterpret_cast<const uint8_t*>(samples);
  const size_t sampleBytesCount =
      static_cast<size_t>(header.sampleCount) * sizeof(BestSwingSample);
  for (size_t i = 0; i < sampleBytesCount; ++i) {
    checksum = checksumStep(checksum, sampleBytes[i]);
  }
  return checksum;
}

uint8_t queuedTelemetryByteAt(uint16_t writeIndex) {
  if (writeIndex < telemetryWriteSampleBytes) {
    const uint8_t* sampleBytes =
        reinterpret_cast<const uint8_t*>(telemetrySamplesToWrite);
    return sampleBytes[writeIndex];
  }
  const uint8_t* headerBytes =
      reinterpret_cast<const uint8_t*>(&telemetryHeaderToWrite);
  return headerBytes[writeIndex - telemetryWriteSampleBytes];
}

size_t queuedTelemetryAddressAt(uint16_t writeIndex) {
  if (writeIndex < telemetryWriteSampleBytes) {
    return sizeof(BestSwingTelemetryHeader) + writeIndex;
  }
  return writeIndex - telemetryWriteSampleBytes;
}

void serviceBestSwingTelemetrySave(uint8_t maxBytes) {
  while (telemetryWritePending && maxBytes > 0) {
    EEPROM.update(
        static_cast<int>(queuedTelemetryAddressAt(telemetryWriteIndex)),
        queuedTelemetryByteAt(telemetryWriteIndex));
    ++telemetryWriteIndex;
    --maxBytes;
    if (telemetryWriteIndex >= telemetryWriteByteCount) {
      telemetryWritePending = false;
    }
  }
}

bool readBestSwingTelemetryHeader(BestSwingTelemetryHeader& header) {
  if (bestTelemetrySampleCapacity() == 0) {
    return false;
  }
  EEPROM.get(0, header);
  if (header.magic != kBestTelemetryMagic ||
      header.version != kBestTelemetryVersion ||
      header.sampleCount > bestTelemetrySampleCapacity()) {
    return false;
  }
  return header.checksum == bestTelemetryChecksumFromEeprom(header.sampleCount);
}

void printBestSwingTelemetryInvalidReason(const BestSwingTelemetryHeader& header) {
  Serial.print(F("status=no_valid_record reason="));
  if (header.magic != kBestTelemetryMagic) {
    Serial.print(F("magic_mismatch stored_magic=0x"));
    Serial.print(header.magic, HEX);
    Serial.print(F(" expected_magic=0x"));
    Serial.println(kBestTelemetryMagic, HEX);
    return;
  }

  if (header.version != kBestTelemetryVersion) {
    Serial.print(F("version_mismatch stored_version="));
    Serial.print(header.version);
    Serial.print(F(" expected_version="));
    Serial.println(kBestTelemetryVersion);
    return;
  }

  const uint8_t sampleCapacity = bestTelemetrySampleCapacity();
  if (header.sampleCount > sampleCapacity) {
    Serial.print(F("sample_count_invalid stored_samples="));
    Serial.print(header.sampleCount);
    Serial.print(F(" capacity="));
    Serial.println(sampleCapacity);
    return;
  }

  const uint8_t expectedChecksum =
      bestTelemetryChecksumFromEeprom(header.sampleCount);
  if (header.checksum != expectedChecksum) {
    Serial.print(F("checksum_mismatch stored_checksum=0x"));
    Serial.print(header.checksum, HEX);
    Serial.print(F(" expected_checksum=0x"));
    Serial.println(expectedChecksum, HEX);
    return;
  }

  Serial.println(F("unknown"));
}

BestSwingSample readBestSwingSample(uint8_t index) {
  BestSwingSample sample = {};
  EEPROM.get(
      static_cast<int>(
          sizeof(BestSwingTelemetryHeader) +
          (static_cast<size_t>(index) * sizeof(BestSwingSample))),
      sample);
  return sample;
}

void endBestSwingTelemetrySerial() {
  Serial.flush();
  Serial.end();
}

void printBestSwingTelemetryOnBoot() {
  Serial.begin(115200);
  delay(80);
  Serial.println();
  Serial.println(F("Dream best swing telemetry"));
  Serial.print(F("header_bytes="));
  Serial.print(sizeof(BestSwingTelemetryHeader));
  Serial.print(F(" sample_bytes="));
  Serial.print(sizeof(BestSwingSample));
  Serial.print(F(" eeprom_bytes="));
  Serial.print(EEPROM.length());
  Serial.print(F(" sample_capacity="));
  Serial.println(bestTelemetrySampleCapacity());

  if (bestTelemetrySampleCapacity() == 0) {
    Serial.println(F("status=record_does_not_fit_eeprom"));
    endBestSwingTelemetrySerial();
    return;
  }

  BestSwingTelemetryHeader telemetry = {};
  if (!readBestSwingTelemetryHeader(telemetry)) {
    printBestSwingTelemetryInvalidReason(telemetry);
    endBestSwingTelemetrySerial();
    return;
  }

  Serial.print(F("score="));
  Serial.print(telemetry.score);
  Serial.print(F(" swing_number="));
  Serial.print(telemetry.swingNumber);
  Serial.print(F(" average_before="));
  Serial.println(telemetry.averageBefore);

  Serial.print(F("duration_ms="));
  Serial.print(telemetry.swingDurationMs);
  Serial.print(F(" sample_total="));
  Serial.print(telemetry.sampleTotal);
  Serial.print(F(" stored_samples="));
  Serial.println(telemetry.sampleCount);

  Serial.print(F("time_origin=start_decision score_start_ms="));
  Serial.print(telemetry.scoreStartMs);
  Serial.print(F(" score_end_ms="));
  Serial.print(telemetry.scoreEndMs);
  Serial.print(F(" accel_peak_ms="));
  Serial.print(telemetry.accelPeakMs);
  Serial.print(F(" decision_end_ms="));
  Serial.println(telemetry.endDecisionMs);
  Serial.print(F("pre_samples="));
  Serial.println(telemetry.preSampleCount);
  Serial.print(F("pre_ring_count="));
  Serial.print(telemetry.preRingCount);
  Serial.print(F(" recent_samples="));
  Serial.print(telemetry.recentSampleCount);
  Serial.print(F(" recent_max_age_ms="));
  Serial.println(telemetry.recentMaxAgeMs);

  Serial.print(F("gyro_score="));
  Serial.println(telemetry.gyroScore);

  Serial.print(F("accel_area_mg_ms="));
  Serial.print(telemetry.accelAreaMgMs);
  Serial.print(F(" accel_score="));
  Serial.println(telemetry.accelScore);

  Serial.println(F("samples_csv=elapsed_ms,gyro_mag_raw,gyro_dps,dynamic_accel_mg"));
  for (uint8_t i = 0; i < telemetry.sampleCount; ++i) {
    const BestSwingSample sample = readBestSwingSample(i);
    Serial.print(sample.elapsedMs);
    Serial.print(',');
    Serial.print(sample.gyroRaw);
    Serial.print(',');
    Serial.print(gyroRawToDps(sample.gyroRaw));
    Serial.print(',');
    Serial.println(sample.accelMg);
  }
  endBestSwingTelemetrySerial();
}

void resetCaptureSamples() {
  for (uint8_t i = 0; i < kCaptureLogSampleCapacity; ++i) {
    captureSamples[i] = {};
  }
  captureSampleWriteIndex = 0;
  captureSampleCount = 0;
  captureSampleTotal = 0;
}
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
void loop() {
  const uint32_t nowMs = millis();
  const uint32_t nowUs = micros();

  Buzzer::update(nowUs);
  if (Buzzer::isActive()) {
    return;
  }
  updateDisplayService();

  if (runMode == RunMode::ShowingScore) {
    if (isTapPollDue(nowMs)) {
      lastTapPollMs = nowMs;
      Imu::readTapEvent();
    } else {
      enterIdleSleep();
    }
    if (static_cast<int32_t>(nowMs - scoreUntilMs) >= 0) {
      runMode = RunMode::Monitor;
    }
    return;
  }

  if (runMode == RunMode::Cooldown) {
    if (isTapPollDue(nowMs)) {
      lastTapPollMs = nowMs;
      Imu::readTapEvent();
    } else {
      enterIdleSleep();
    }
    if (static_cast<int32_t>(nowMs - cooldownUntilMs) >= 0) {
      runMode = RunMode::Monitor;
    }
    return;
  }

  if (runMode == RunMode::Monitor) {
    if (static_cast<int32_t>(nowMs - tapMutedUntilMs) < 0) {
      if (isTapPollDue(nowMs)) {
        lastTapPollMs = nowMs;
        Imu::readTapEvent();
      }
    } else if (isTapPollDue(nowMs)) {
      lastTapPollMs = nowMs;
      const TapEvent tapEvent = Imu::readTapEvent();
      handleMonitorTapEvent(tapEvent, nowMs);
      if (tapEvent != TapEvent::None) {
        return;
      }
      if (runMode != RunMode::Monitor) {
        return;
      }
    }
  }

  const bool imuInterrupted = Imu::consumeInterruptCount() != 0;
  if (imuInterrupted) {
    lastImuInterruptMs = nowMs;
  }
  const bool forceImuRead =
      !imuInterrupted && runMode != RunMode::Calibrate && isInterruptStalled(nowMs);
  if (!imuInterrupted && runMode != RunMode::Calibrate && !forceImuRead) {
    if (runMode == RunMode::Monitor) {
      if (isIdleTimedOut(nowMs) && !telemetryWritePending) {
        enterFinalSleep();
      }
      if (!Display::isOn(nowMs)) {
        serviceBestSwingTelemetrySave(kTelemetryEepromBytesPerService);
      }
      enterIdleSleep();
    }
    return;
  }
  if (forceImuRead) {
    lastImuInterruptMs = nowMs;
  }

  uint16_t accelMagnitudeMg = 0;
  int16_t gyroXRaw = 0;
  int16_t gyroYRaw = 0;
  int16_t gyroZRaw = 0;
  Imu::readMotionSample(accelMagnitudeMg, gyroXRaw, gyroYRaw, gyroZRaw);

  if (runMode == RunMode::Calibrate) {
    if (calibrationSamples < 32767) {
      gyroXSum += gyroXRaw;
      gyroYSum += gyroYRaw;
      gyroZSum += gyroZRaw;
      accelSumMg += accelMagnitudeMg;
      ++calibrationSamples;
    }
    if (static_cast<int32_t>(nowMs - calibrationUntilMs) >= 0) {
      finishCalibration();
    }
    Imu::drainFifo();
    updateDisplayService();
    return;
  }

  const int16_t dynamicGyroXRaw = static_cast<int16_t>(gyroXRaw - gyroBaselineX);
  const int16_t dynamicGyroYRaw = static_cast<int16_t>(gyroYRaw - gyroBaselineY);
  const int16_t dynamicGyroZRaw = static_cast<int16_t>(gyroZRaw - gyroBaselineZ);
  const uint16_t gyroMagnitudeRaw =
      magnitudeRaw(dynamicGyroXRaw, dynamicGyroYRaw, dynamicGyroZRaw);

  const uint16_t dynamicAccelMg = absDiff16(accelMagnitudeMg, accelBaselineMg);
  if (dynamicAccelMg < kBaselineTrackDeltaMg) {
    const int32_t baselineDeltaMg =
        static_cast<int32_t>(accelMagnitudeMg) - static_cast<int32_t>(accelBaselineMg);
    accelBaselineMg = static_cast<uint16_t>(
        static_cast<int32_t>(accelBaselineMg) + (baselineDeltaMg >> 5));
  }

  const uint32_t strength =
      static_cast<uint32_t>(gyroMagnitudeRaw) +
      static_cast<uint32_t>(dynamicAccelMg) * 4UL;
  const uint16_t liftStrength = saturateToUint16(strength);

  if (runMode == RunMode::Monitor) {
    updateMotionCandidate(strength, nowMs);
    recordPreCaptureSample(nowMs, gyroMagnitudeRaw, dynamicAccelMg);

    if (isCaptureStartMotion(strength, gyroMagnitudeRaw, dynamicAccelMg)) {
      Imu::readTapEvent();
      lastActivityMs = nowMs;
      startCapture(nowMs, liftStrength, captureStartTimeFor(nowMs), true);
      updateCapturePeaks(
          gyroMagnitudeRaw,
          dynamicAccelMg,
          liftStrength,
          nowMs);
      Imu::drainFifo();
      updateDisplayService();
      return;
    }

    if (isIdleTimedOut(nowMs)) {
      enterFinalSleep();
    }
    Imu::drainFifo();
    updateDisplayService();
    return;
  }

  if (runMode != RunMode::Capturing) {
    Imu::drainFifo();
    updateDisplayService();
    return;
  }

  Imu::readTapEvent();

  const uint16_t strength16 = liftStrength;
  if (strength16 > capturePeakStrength) {
    if (static_cast<uint32_t>(strength16) >=
        static_cast<uint32_t>(capturePeakStrength) + kCaptureRestartStrength) {
      startCapture(nowMs, strength16, nowMs, true);
    } else {
      capturePeakStrength = strength16;
    }
  }
  updateCapturePeaks(
      gyroMagnitudeRaw,
      dynamicAccelMg,
      strength16,
      nowMs);

  if (isCaptureFinished(strength16, nowMs)) {
    finishCapture(nowMs);
  }
  Imu::drainFifo();
  updateDisplayService();
}

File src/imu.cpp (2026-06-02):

#include "imu.h"

#include <SPI.h>

namespace {

const uint8_t kCsPin = PIN_PA4;
const uint8_t kReadBit = 0x80;

const uint8_t kRegWhoAmI = 0x0F;
const uint8_t kRegFifoCtrl1 = 0x07;
const uint8_t kRegFifoCtrl2 = 0x08;
const uint8_t kRegFifoCtrl3 = 0x09;
const uint8_t kRegFifoCtrl4 = 0x0A;
const uint8_t kRegCounterBdr1 = 0x0B;
const uint8_t kRegInt1Ctrl = 0x0D;
const uint8_t kRegCtrl1 = 0x10;
const uint8_t kRegCtrl2 = 0x11;
const uint8_t kRegCtrl3 = 0x12;
const uint8_t kRegCtrl6 = 0x15;
const uint8_t kRegCtrl8 = 0x17;
const uint8_t kRegFifoStatus1 = 0x1B;
const uint8_t kRegFifoStatus2 = 0x1C;
const uint8_t kRegTapSrc = 0x46;
const uint8_t kRegOutXG = 0x22;
const uint8_t kRegOutXHg = 0x34;
const uint8_t kRegCtrl1Hg = 0x4E;
const uint8_t kRegFunctionsEnable = 0x50;
const uint8_t kRegTapCfg0 = 0x56;
const uint8_t kRegTapCfg1 = 0x57;
const uint8_t kRegTapCfg2 = 0x58;
const uint8_t kRegTapThs6d = 0x59;
const uint8_t kRegTapDur = 0x5A;
const uint8_t kRegWakeUpThs = 0x5B;
const uint8_t kRegWakeUpDur = 0x5C;
const uint8_t kRegMd1Cfg = 0x5E;
const uint8_t kRegFifoDataOutTag = 0x78;

const uint8_t kWhoAmI = 0x73;
const uint8_t kCtrl1Accel480Hz = 0x08;
const uint8_t kCtrl1AccelPowerDown = 0x00;
const uint8_t kCtrl2Gyro480Hz = 0x08;
const uint8_t kCtrl2GyroPowerDown = 0x00;
const uint8_t kCtrl3BduIfInc = 0x44;
const uint8_t kCtrl6Gyro4000dps = 0x0D;
const uint8_t kCtrl8Accel8g = 0x02;
const uint8_t kCtrl1HighGAccel480Hz64g = 0x66;
const uint8_t kCtrl1HighGAccelPowerDown = 0x00;

const uint8_t kInt1Pin = PIN_PA5;
const uint8_t kTapCfg0EnableZLatched = 0x03;
const uint8_t kTapThreshold = 0x01;
const uint8_t kTapDurDoubleTap = 0x46;
const uint8_t kWakeUpThsSingleDoubleTap = 0x80;
const uint8_t kWakeUpDurNoDuration = 0x00;
const uint8_t kFunctionsEnableEmbeddedFunctions = 0x80;
const uint8_t kMd1CfgTapOnInt1 = 0x48;
const uint8_t kInt1CtrlFifoWatermark = 0x08;
const uint8_t kTapSrcSingleTap = 0x20;
const uint8_t kTapSrcDoubleTap = 0x10;
const uint8_t kFifoWatermarkEntries = 8;
const uint8_t kFifoBdrGyro480Hz = 0x80;
const uint8_t kCounterBdrHighGAccelBatch = 0x08;
const uint8_t kFifoModeBypass = 0x00;
const uint8_t kFifoModeContinuous = 0x06;
const uint8_t kFifoEntrySizeBytes = 7;
const uint8_t kFifoStatus2DiffFifoHighMask = 0x03;
const uint16_t kFifoDrainMaxEntries = 96;
const uint16_t kFifoEntryApproxUs = 2083;
const uint8_t kFifoTagSensorShift = 3;
const uint8_t kFifoTagGyro = 0x01;
const uint8_t kFifoTagHighGAccel = 0x1D;
const uint8_t kRecentMotionSnapshotCapacity = 32;

bool ready = false;
volatile uint8_t int1Count = 0;
Imu::MotionSnapshot recentMotionSnapshots[kRecentMotionSnapshotCapacity] = {};
uint8_t recentMotionSnapshotCountValue = 0;
uint16_t lastMotionAccelMagnitudeMg = 1000;
int16_t lastMotionGyroXRaw = 0;
int16_t lastMotionGyroYRaw = 0;
int16_t lastMotionGyroZRaw = 0;

SPISettings spiSettings(1000000, MSBFIRST, SPI_MODE3);

void onInt1() {
  if (int1Count < 255) {
    ++int1Count;
  }
}

uint8_t readRegister(uint8_t reg) {
  SPI.beginTransaction(spiSettings);
  digitalWrite(kCsPin, LOW);
  SPI.transfer(reg | kReadBit);
  const uint8_t value = SPI.transfer(0x00);
  digitalWrite(kCsPin, HIGH);
  SPI.endTransaction();
  return value;
}

void writeRegister(uint8_t reg, uint8_t value) {
  SPI.beginTransaction(spiSettings);
  digitalWrite(kCsPin, LOW);
  SPI.transfer(reg);
  SPI.transfer(value);
  digitalWrite(kCsPin, HIGH);
  SPI.endTransaction();
}

void readRegisters(uint8_t startReg, uint8_t* buffer, uint8_t count) {
  SPI.beginTransaction(spiSettings);
  digitalWrite(kCsPin, LOW);
  SPI.transfer(startReg | kReadBit);
  for (uint8_t i = 0; i < count; ++i) {
    buffer[i] = SPI.transfer(0x00);
  }
  digitalWrite(kCsPin, HIGH);
  SPI.endTransaction();
}

void readAxesRaw(uint8_t startReg, int16_t& x, int16_t& y, int16_t& z) {
  uint8_t bytes[6] = {};
  readRegisters(startReg, bytes, sizeof(bytes));
  x = static_cast<int16_t>((static_cast<uint16_t>(bytes[1]) << 8) | bytes[0]);
  y = static_cast<int16_t>((static_cast<uint16_t>(bytes[3]) << 8) | bytes[2]);
  z = static_cast<int16_t>((static_cast<uint16_t>(bytes[5]) << 8) | bytes[4]);
}

uint16_t isqrt(uint32_t value) {
  uint32_t bit = 1UL << 30;
  uint32_t result = 0;

  while (bit > value) {
    bit >>= 2;
  }

  while (bit != 0) {
    if (value >= result + bit) {
      value -= result + bit;
      result = (result >> 1) + bit;
    } else {
      result >>= 1;
    }
    bit >>= 2;
  }

  return static_cast<uint16_t>(result);
}

int32_t highGRawToMg(int16_t raw) {
  // High-g accelerometer at +/-64 g is 1.953 mg/LSB.
  return (static_cast<int32_t>(raw) * 1953L) / 1000L;
}

uint32_t squareInt16(int16_t value) {
  const int32_t wideValue = value;
  return static_cast<uint32_t>(wideValue * wideValue);
}

void configureTapDetection() {
  writeRegister(kRegTapCfg0, kTapCfg0EnableZLatched);
  writeRegister(kRegTapCfg1, 0x00);
  writeRegister(kRegTapCfg2, 0x00);
  writeRegister(kRegTapThs6d, kTapThreshold);
  writeRegister(kRegTapDur, kTapDurDoubleTap);
  writeRegister(kRegWakeUpThs, kWakeUpThsSingleDoubleTap);
  writeRegister(kRegWakeUpDur, kWakeUpDurNoDuration);
  writeRegister(kRegFunctionsEnable, kFunctionsEnableEmbeddedFunctions);
  writeRegister(kRegMd1Cfg, kMd1CfgTapOnInt1);
  readRegister(kRegTapSrc);
}

void configureFullRateSensors() {
  writeRegister(kRegCtrl8, kCtrl8Accel8g);
  writeRegister(kRegCtrl1, kCtrl1Accel480Hz);
  writeRegister(kRegCtrl1Hg, kCtrl1HighGAccel480Hz64g);
  writeRegister(kRegCtrl6, kCtrl6Gyro4000dps);
  writeRegister(kRegCtrl2, kCtrl2Gyro480Hz);
}

uint16_t fifoEntryCount() {
  const uint8_t status1 = readRegister(kRegFifoStatus1);
  const uint8_t status2 = readRegister(kRegFifoStatus2);
  return static_cast<uint16_t>(
      status1 |
      ((static_cast<uint16_t>(status2 & kFifoStatus2DiffFifoHighMask)) << 8));
}

void configureFifo() {
  writeRegister(kRegFifoCtrl4, kFifoModeBypass);
  writeRegister(kRegCounterBdr1, kCounterBdrHighGAccelBatch);
  writeRegister(kRegFifoCtrl1, kFifoWatermarkEntries);
  writeRegister(kRegFifoCtrl2, 0x00);
  writeRegister(kRegFifoCtrl3, kFifoBdrGyro480Hz);
  writeRegister(kRegFifoCtrl4, kFifoModeContinuous);
}

void configureFifoInterrupt() {
  writeRegister(kRegInt1Ctrl, kInt1CtrlFifoWatermark);
}

void rememberMotionSnapshot(
    uint16_t accelMagnitudeMg,
    int16_t gyroXRaw,
    int16_t gyroYRaw,
    int16_t gyroZRaw,
    uint16_t ageMs) {
  if (recentMotionSnapshotCountValue >= kRecentMotionSnapshotCapacity) {
    for (uint8_t i = 1; i < kRecentMotionSnapshotCapacity; ++i) {
      recentMotionSnapshots[i - 1] = recentMotionSnapshots[i];
    }
    recentMotionSnapshotCountValue = kRecentMotionSnapshotCapacity - 1;
  }

  recentMotionSnapshots[recentMotionSnapshotCountValue] = {
      accelMagnitudeMg,
      gyroXRaw,
      gyroYRaw,
      gyroZRaw,
      ageMs,
  };
  ++recentMotionSnapshotCountValue;
}

}  // namespace

namespace Imu {
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

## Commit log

2026-04-23 Add initial project configuration and documentation files
    - Create .gitignore to exclude build artifacts and IDE settings
    - Add .vscode/extensions.json for recommended extensions
    - Include README files for header files, libraries, and tests
    - Set up platformio.ini for ATtiny3226 configuration
    - Implement main.cpp for basic LED blinking functionality
    [Dream.kicad_pcb, Dream.kicad_sch, bom.csv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]
2026-05-11 Rename home filter section
2026-05-11 Remove home filter heading
2026-05-11 Tighten bat selector design
2026-05-11 Compact home filters
2026-05-11 Balance home filter columns
2026-05-11 Stack home filters vertically
2026-05-11 Remove chart axis frame
2026-05-11 Switch to accent color themes
2026-05-12 Move filters above score summary
2026-05-12 Hide incomplete meter track
2026-05-12 Restore chart styling and add y-axis
2026-05-12 Strengthen chart y-axis visibility
2026-05-12 Tighten home tab labels
2026-05-12 Switch flat styling to dark mode
2026-05-12 Refine home filter and date heading
2026-05-12 Tighten tabs and neutralize card borders
2026-05-13 Tone down calendar edit button
2026-05-13 Prototype version 2 home cards
2026-05-14 Remove score badge frame
2026-05-15 チャレンジ画面の記録レイアウトを更新
2026-05-15 ホームと記録画面のUIを調整
2026-05-15 使ったバット見出しの位置を調整
2026-05-15 記録タブのスコアカード表示を調整
2026-05-15 チャレンジと記録のカード列数を調整
2026-05-15 Refine challenge and data flows
2026-05-15 Tune input animation test flow
2026-05-15 Fix input button recovery state
2026-05-16 Match home input OK button styling
2026-05-16 Save current swing log layout state
2026-05-25 Refine badge plates and UI styling
2026-05-28 badge-list.md を更新
